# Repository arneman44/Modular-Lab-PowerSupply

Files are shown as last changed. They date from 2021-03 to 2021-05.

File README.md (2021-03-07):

# Project Modular lab powersupply
Arne Van den Broeck

## Desciption
A Modular lab bench powersupply 

### Specs Modules:
* use the eurocard format
* connected via a 40 ribbon cable as a bus 
* its own isolated powersupply 

## Modules:

### Powermodule:
* 0-30V
* 0-3A
* 16bit readout
* 12bit Controll
* Dual powerbus for connecting modules internally

### controller:
* 7inch touchscreen
* Ethernet
* USB host/device
* rotary Encoder

## Future modules:
* DC load
* Waveform generator
* Multimeter
* GPIO

## Files 
All the Kicad files where made using the nightly build of kicad
Version: (5.99.0-9544-g366189b864)

The STM32 project are build with cubeMX with as toolchain makefile.
I use vscode with STM32-for-vscode to build it

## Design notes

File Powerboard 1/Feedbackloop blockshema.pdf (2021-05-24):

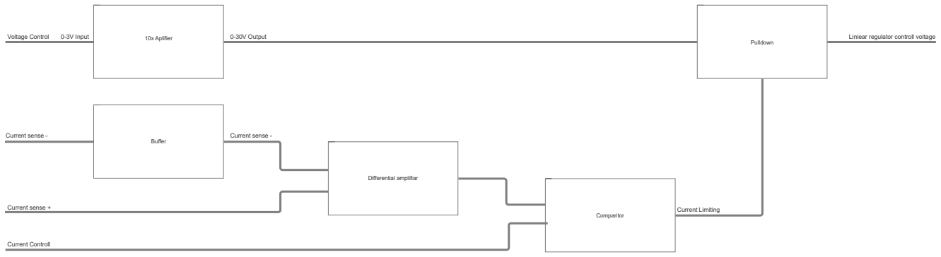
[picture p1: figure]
10x Aplifier; Buffer; Voltage Control; 0-3V Input; 0-30V Output; Pulldown; Current sense -; Current sense +; Differential amplifiar; Comparitor; Current Controll; Liniear regulator controll voltage; Current Limiting

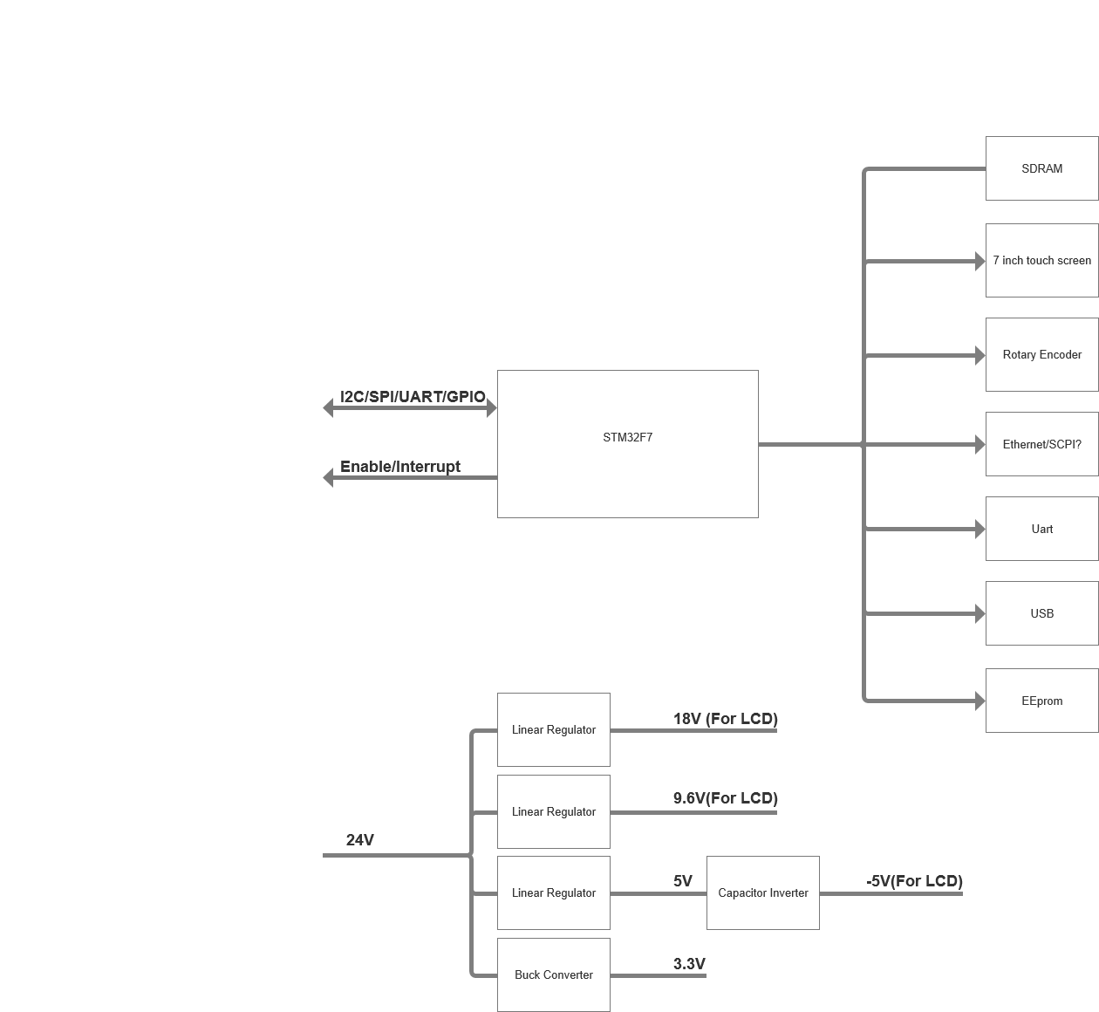
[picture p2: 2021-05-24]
Docs/contoller.png

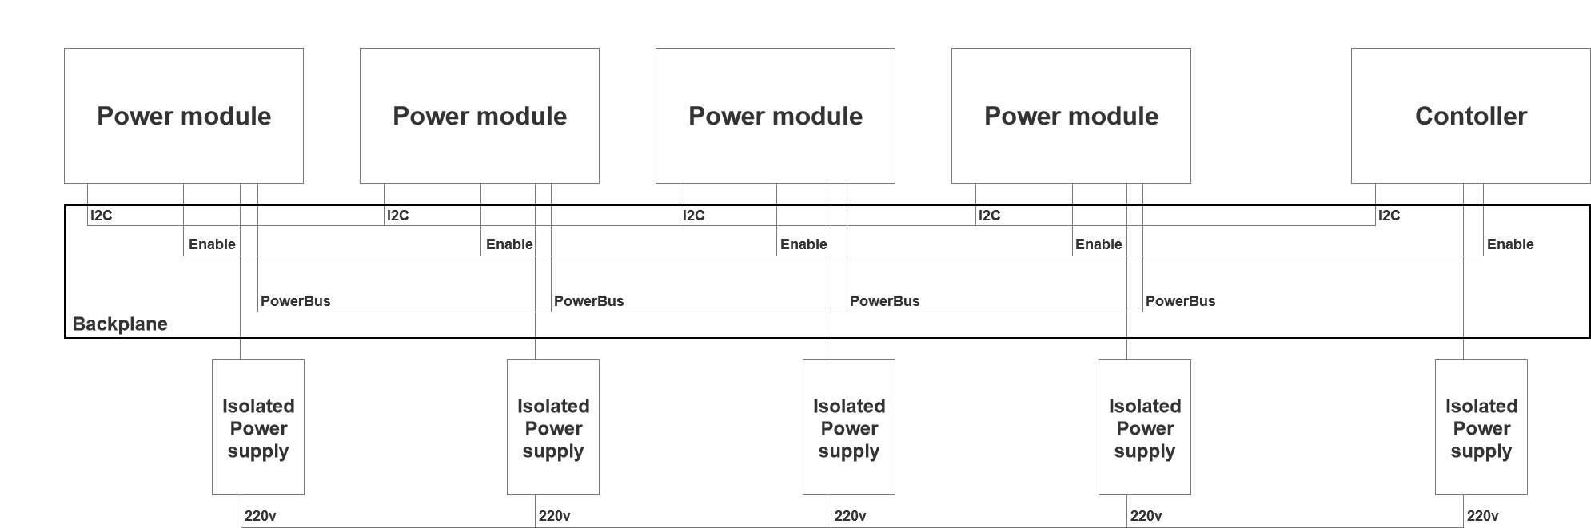
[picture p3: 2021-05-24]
Docs/power_supply.png

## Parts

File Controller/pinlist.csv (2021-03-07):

Position | Name | Type | Signal | Label | AF0 | AF1 | AF2 | AF3 | AF4 | AF5 | AF6 | AF7 | AF8 | AF9 | AF10 | AF11 | AF12 | AF13 | AF14
1 | PE2 | I/O |  |  | SYS_TRACECLK |  |  |  |  | SPI4_SCK | SAI1_MCLK_A |  |  | QUADSPI_BK1_IO2 |  | ETH_TXD3 | FMC_A23
2 | PE3 | I/O |  |  | SYS_TRACED0 |  |  |  |  |  | SAI1_SD_B |  |  |  |  |  | FMC_A19
3 | PE4 | I/O | LTDC_B0 |  | SYS_TRACED1 |  |  |  |  | SPI4_NSS | SAI1_FS_A |  |  |  |  |  | FMC_A20 | DCMI_D4 | LTDC_B0
4 | PE5 | I/O | LTDC_G0 |  | SYS_TRACED2 |  |  | TIM9_CH1 |  | SPI4_MISO | SAI1_SCK_A |  |  |  |  |  | FMC_A21 | DCMI_D6 | LTDC_G0
5 | PE6 | I/O | LTDC_G1 |  | SYS_TRACED3 | TIM1_BKIN2 |  | TIM9_CH2 |  | SPI4_MOSI | SAI1_SD_A |  |  |  | SAI2_MCLK_B |  | FMC_A22 | DCMI_D7 | LTDC_G1
6 | VBAT | Power
7 | PI8 | I/O
8 | PC13 | I/O
9 | PC14/OSC32_IN | I/O | RCC_OSC32_IN
10 | PC15/OSC32_OUT | I/O | RCC_OSC32_OUT
11 | PI9 | I/O | LTDC_VSYNC |  |  |  |  |  |  |  |  |  |  | CAN1_RX |  |  | FMC_D30 |  | LTDC_VSYNC
12 | PI10 | I/O | LTDC_HSYNC |  |  |  |  |  |  |  |  |  |  |  |  | ETH_RX_ER | FMC_D31 |  | LTDC_HSYNC
13 | PI11 | I/O |  |  |  |  |  |  |  |  |  |  |  |  | USB_OTG_HS_ULPI_DIR
14 | VSS | Power
15 | VDD | Power
16 | PF0 | I/O | I2C2_SDA |  |  |  |  |  | I2C2_SDA |  |  |  |  |  |  |  | FMC_A0
17 | PF1 | I/O | I2C2_SCL |  |  |  |  |  | I2C2_SCL |  |  |  |  |  |  |  | FMC_A1
18 | PF2 | I/O |  |  |  |  |  |  | I2C2_SMBA |  |  |  |  |  |  |  | FMC_A2
19 | PF3 | I/O |  |  |  |  |  |  |  |  |  |  |  |  |  |  | FMC_A3
20 | PF4 | I/O |  |  |  |  |  |  |  |  |  |  |  |  |  |  | FMC_A4
21 | PF5 | I/O |  |  |  |  |  |  |  |  |  |  |  |  |  |  | FMC_A5
22 | VSS | Power
23 | VDD | Power
24 | PF6 | I/O | UART7_RX |  |  |  |  | TIM10_CH1 |  | SPI5_NSS | SAI1_SD_B |  | UART7_RX | QUADSPI_BK1_IO3
25 | PF7 | I/O | UART7_TX |  |  |  |  | TIM11_CH1 |  | SPI5_SCK | SAI1_MCLK_B |  | UART7_TX | QUADSPI_BK1_IO2
26 | PF8 | I/O |  |  |  |  |  |  |  | SPI5_MISO | SAI1_SCK_B |  | UART7_DE/UART7_RTS | TIM13_CH1 | QUADSPI_BK1_IO0
27 | PF9 | I/O |  |  |  |  |  |  |  | SPI5_MOSI | SAI1_FS_B |  | UART7_CTS | TIM14_CH1 | QUADSPI_BK1_IO1
28 | PF10 | I/O | LTDC_DE |  |  |  |  |  |  |  |  |  |  |  |  |  |  | DCMI_D11 | LTDC_DE
29 | PH0/OSC_IN | I/O | RCC_OSC_IN
30 | PH1/OSC_OUT | I/O | RCC_OSC_OUT
31 | NRST | Reset
32 | PC0 | I/O | LTDC_R5 |  |  |  |  |  |  |  |  |  | SAI2_FS_B |  | USB_OTG_HS_ULPI_STP |  | FMC_SDNWE |  | LTDC_R5
33 | PC1 | I/O | ETH_MDC |  | SYS_TRACED0 |  |  |  |  | I2S2_SD/SPI2_MOSI | SAI1_SD_A |  |  |  |  | ETH_MDC
34 | PC2 | I/O | SPI2_MISO |  |  |  |  |  |  | SPI2_MISO |  |  |  |  | USB_OTG_HS_ULPI_DIR | ETH_TXD2 | FMC_SDNE0
35 | PC3 | I/O | SPI2_MOSI |  |  |  |  |  |  | I2S2_SD/SPI2_MOSI |  |  |  |  | USB_OTG_HS_ULPI_NXT | ETH_TX_CLK | FMC_SDCKE0
36 | VDD | Power
37 | VSSA | Power
38 | VREF+ | Power
39 | VDDA | Power
40 | PA0/WKUP | I/O | UART4_TX |  |  | TIM2_CH1/TIM2_ETR | TIM5_CH1 | TIM8_ETR |  |  |  | USART2_CTS | UART4_TX |  | SAI2_SD_B | ETH_CRS
41 | PA1 | I/O | ETH_REF_CLK |  |  | TIM2_CH2 | TIM5_CH2 |  |  |  |  | USART2_DE/USART2_RTS | UART4_RX | QUADSPI_BK1_IO3 | SAI2_MCLK_B | ETH_REF_CLK/ETH_RX_CLK |  |  | LTDC_R2
42 | PA2 | I/O | ETH_MDIO |  |  | TIM2_CH3 | TIM5_CH3 | TIM9_CH1 |  |  |  | USART2_TX | SAI2_SCK_B |  |  | ETH_MDIO |  |  | LTDC_R1
43 | PH2 | I/O | LTDC_R0 |  |  |  |  | LPTIM1_IN2 |  |  |  |  |  | QUADSPI_BK2_IO0 | SAI2_SCK_B | ETH_CRS | FMC_SDCKE0 |  | LTDC_R0
44 | PH3 | I/O | LTDC_R1 |  |  |  |  |  |  |  |  |  |  | QUADSPI_BK2_IO1 | SAI2_MCLK_B | ETH_COL | FMC_SDNE0 |  | LTDC_R1
45 | PH4 | I/O |  |  |  |  |  |  | I2C2_SCL |  |  |  |  |  | USB_OTG_HS_ULPI_NXT
46 | PH5 | I/O |  |  |  |  |  |  | I2C2_SDA | SPI5_NSS |  |  |  |  |  |  | FMC_SDNWE
47 | PA3 | I/O | USART2_RX |  |  | TIM2_CH4 | TIM5_CH4 | TIM9_CH2 |  |  |  | USART2_RX |  |  | USB_OTG_HS_ULPI_D0 | ETH_COL |  |  | LTDC_B5
48 | BYPASS_REG | Reset
49 | VDD | Power
50 | PA4 | I/O | DAC_OUT1 |  |  |  |  |  |  | I2S1_WS/SPI1_NSS | I2S3_WS/SPI3_NSS | USART2_CK |  |  |  |  | USB_OTG_HS_SOF | DCMI_HSYNC | LTDC_VSYNC
51 | PA5 | I/O | SPI1_SCK |  |  | TIM2_CH1/TIM2_ETR |  | TIM8_CH1N |  | I2S1_CK/SPI1_SCK |  |  |  |  | USB_OTG_HS_ULPI_CK |  |  |  | LTDC_R4
52 | PA6 | I/O | LTDC_G2 |  |  | TIM1_BKIN | TIM3_CH1 | TIM8_BKIN |  | SPI1_MISO |  |  |  | TIM13_CH1 |  |  |  | DCMI_PIXCLK | LTDC_G2
53 | PA7 | I/O | ETH_CRS_DV |  |  | TIM1_CH1N | TIM3_CH2 | TIM8_CH1N |  | I2S1_SD/SPI1_MOSI |  |  |  | TIM14_CH1 |  | ETH_CRS_DV/ETH_RX_DV | FMC_SDNWE
54 | PC4 | I/O | ETH_RXD0 |  |  |  |  |  |  | I2S1_MCK |  |  | SPDIFRX_IN2 |  |  | ETH_RXD0 | FMC_SDNE0
55 | PC5 | I/O | ETH_RXD1 |  |  |  |  |  |  |  |  |  | SPDIFRX_IN3 |  |  | ETH_RXD1 | FMC_SDCKE0
56 | PB0 | I/O | LTDC_R3 |  |  | TIM1_CH2N | TIM3_CH3 | TIM8_CH2N |  |  |  |  | UART4_CTS | LTDC_R3 | USB_OTG_HS_ULPI_D1 | ETH_RXD2
57 | PB1 | I/O | LTDC_R6 |  |  | TIM1_CH3N | TIM3_CH4 | TIM8_CH3N |  |  |  |  |  | LTDC_R6 | USB_OTG_HS_ULPI_D2 | ETH_RXD3
58 | PB2 | I/O |  |  |  |  |  |  |  |  | SAI1_SD_A | I2S3_SD/SPI3_MOSI |  | QUADSPI_CLK
59 | PF11 | I/O |  |  |  |  |  |  |  | SPI5_MOSI |  |  |  |  | SAI2_SD_B |  | FMC_SDNRAS | DCMI_D12
60 | PF12 | I/O |  |  |  |  |  |  |  |  |  |  |  |  |  |  | FMC_A6
61 | VSS | Power
62 | VDD | Power
63 | PF13 | I/O |  |  |  |  |  |  | I2C4_SMBA |  |  |  |  |  |  |  | FMC_A7
64 | PF14 | I/O |  |  |  |  |  |  | I2C4_SCL |  |  |  |  |  |  |  | FMC_A8
65 | PF15 | I/O |  |  |  |  |  |  | I2C4_SDA |  |  |  |  |  |  |  | FMC_A9
66 | PG0 | I/O |  |  |  |  |  |  |  |  |  |  |  |  |  |  | FMC_A10
67 | PG1 | I/O |  |  |  |  |  |  |  |  |  |  |  |  |  |  | FMC_A11
68 | PE7 | I/O |  |  |  | TIM1_ETR |  |  |  |  |  |  | UART7_RX |  | QUADSPI_BK2_IO0 |  | FMC_D4/FMC_DA4
69 | PE8 | I/O |  |  |  | TIM1_CH1N |  |  |  |  |  |  | UART7_TX |  | QUADSPI_BK2_IO1 |  | FMC_D5/FMC_DA5
70 | PE9 | I/O | TIM1_CH1 |  |  | TIM1_CH1 |  |  |  |  |  |  | UART7_DE/UART7_RTS |  | QUADSPI_BK2_IO2 |  | FMC_D6/FMC_DA6
71 | VSS | Power
72 | VDD | Power
73 | PE10 | I/O |  |  |  | TIM1_CH2N |  |  |  |  |  |  | UART7_CTS |  | QUADSPI_BK2_IO3 |  | FMC_D7/FMC_DA7
74 | PE11 | I/O | TIM1_CH2 |  |  | TIM1_CH2 |  |  |  | SPI4_NSS |  |  |  |  | SAI2_SD_B |  | FMC_D8/FMC_DA8 |  | LTDC_G3
75 | PE12 | I/O | LTDC_B4 |  |  | TIM1_CH3N |  |  |  | SPI4_SCK |  |  |  |  | SAI2_SCK_B |  | FMC_D9/FMC_DA9 |  | LTDC_B4
76 | PE13 | I/O | TIM1_CH3 |  |  | TIM1_CH3 |  |  |  | SPI4_MISO |  |  |  |  | SAI2_FS_B |  | FMC_D10/FMC_DA10 |  | LTDC_DE
77 | PE14 | I/O | TIM1_CH4 |  |  | TIM1_CH4 |  |  |  | SPI4_MOSI |  |  |  |  | SAI2_MCLK_B |  | FMC_D11/FMC_DA11 |  | LTDC_CLK
78 | PE15 | I/O | LTDC_R7 |  |  | TIM1_BKIN |  |  |  |  |  |  |  |  |  |  | FMC_D12/FMC_DA12 |  | LTDC_R7
79 | PB10 | I/O | TIM2_CH3 |  |  | TIM2_CH3 |  |  | I2C2_SCL | I2S2_CK/SPI2_SCK |  | USART3_TX |  |  | USB_OTG_HS_ULPI_D3 | ETH_RX_ER |  |  | LTDC_G4
80 | PB11 | I/O | TIM2_CH4 |  |  | TIM2_CH4 |  |  | I2C2_SDA |  |  | USART3_RX |  |  | USB_OTG_HS_ULPI_D4 | ETH_TX_EN |  |  | LTDC_G5
81 | VCAP_1 | Power
82 | VDD | Power
83 | PH6 | I/O |  |  |  |  |  |  | I2C2_SMBA | SPI5_SCK |  |  |  | TIM12_CH1 |  | ETH_RXD2 | FMC_SDNE1 | DCMI_D8
84 | PH7 | I/O | I2C3_SCL |  |  |  |  |  | I2C3_SCL | SPI5_MISO |  |  |  |  |  | ETH_RXD3 | FMC_SDCKE1 | DCMI_D9
85 | PH8 | I/O | LTDC_R2 |  |  |  |  |  | I2C3_SDA |  |  |  |  |  |  |  | FMC_D16 | DCMI_HSYNC | LTDC_R2
86 | PH9 | I/O |  |  |  |  |  |  | I2C3_SMBA |  |  |  |  | TIM12_CH2 |  |  | FMC_D17 | DCMI_D0 | LTDC_R3
87 | PH10 | I/O | LTDC_R4 |  |  |  | TIM5_CH1 |  | I2C4_SMBA |  |  |  |  |  |  |  | FMC_D18 | DCMI_D1 | LTDC_R4
88 | PH11 | I/O |  |  |  |  | TIM5_CH2 |  | I2C4_SCL |  |  |  |  |  |  |  | FMC_D19 | DCMI_D2 | LTDC_R5
89 | PH12 | I/O |  |  |  |  | TIM5_CH3 |  | I2C4_SDA |  |  |  |  |  |  |  | FMC_D20 | DCMI_D3 | LTDC_R6
90 | VSS | Power
91 | VDD | Power
92 | PB12 | I/O | ETH_TXD0 |  |  | TIM1_BKIN |  |  | I2C2_SMBA | I2S2_WS/SPI2_NSS |  | USART3_CK |  | CAN2_RX | USB_OTG_HS_ULPI_D5 | ETH_TXD0 | USB_OTG_HS_ID
93 | PB13 | I/O | ETH_TXD1 |  |  | TIM1_CH1N |  |  |  | I2S2_CK/SPI2_SCK |  | USART3_CTS |  | CAN2_TX | USB_OTG_HS_ULPI_D6 | ETH_TXD1
94 | PB14 | I/O |  |  |  | TIM1_CH2N |  | TIM8_CH2N |  | SPI2_MISO |  | USART3_DE/USART3_RTS |  | TIM12_CH1 |  |  | USB_OTG_HS_DM
95 | PB15 | I/O |  |  | RTC_REFIN | TIM1_CH3N |  | TIM8_CH3N |  | I2S2_SD/SPI2_MOSI |  |  |  | TIM12_CH2 |  |  | USB_OTG_HS_DP
96 | PD8 | I/O | USART3_TX |  |  |  |  |  |  |  |  | USART3_TX | SPDIFRX_IN1 |  |  |  | FMC_D13/FMC_DA13
97 | PD9 | I/O | USART3_RX |  |  |  |  |  |  |  |  | USART3_RX |  |  |  |  | FMC_D14/FMC_DA14
98 | PD10 | I/O | LTDC_B3 |  |  |  |  |  |  |  |  | USART3_CK |  |  |  |  | FMC_D15/FMC_DA15 |  | LTDC_B3
99 | PD11 | I/O |  |  |  |  |  |  | I2C4_SMBA |  |  | USART3_CTS |  | QUADSPI_BK1_IO0 | SAI2_SD_A |  | FMC_A16/FMC_CLE
100 | PD12 | I/O |  |  |  |  | TIM4_CH1 | LPTIM1_IN1 | I2C4_SCL |  |  | USART3_DE/USART3_RTS |  | QUADSPI_BK1_IO1 | SAI2_FS_A |  | FMC_A17/FMC_ALE
101 | PD13 | I/O |  |  |  |  | TIM4_CH2 | LPTIM1_OUT | I2C4_SDA |  |  |  |  | QUADSPI_BK1_IO3 | SAI2_SCK_A |  | FMC_A18
102 | VSS | Power
103 | VDD | Power
104 | PD14 | I/O |  |  |  |  | TIM4_CH3 |  |  |  |  |  | UART8_CTS |  |  |  | FMC_D0/FMC_DA0
105 | PD15 | I/O |  |  |  |  | TIM4_CH4 |  |  |  |  |  | UART8_DE/UART8_RTS |  |  |  | FMC_D1/FMC_DA1
106 | PG2 | I/O |  |  |  |  |  |  |  |  |  |  |  |  |  |  | FMC_A12
107 | PG3 | I/O |  |  |  |  |  |  |  |  |  |  |  |  |  |  | FMC_A13
108 | PG4 | I/O |  |  |  |  |  |  |  |  |  |  |  |  |  |  | FMC_A14/FMC_BA0
109 | PG5 | I/O |  |  |  |  |  |  |  |  |  |  |  |  |  |  | FMC_A15/FMC_BA1
110 | PG6 | I/O |  |  |  |  |  |  |  |  |  |  |  |  |  |  |  | DCMI_D12 | LTDC_R7
111 | PG7 | I/O | LTDC_CLK |  |  |  |  |  |  |  |  |  | USART6_CK |  |  |  | FMC_INT | DCMI_D13 | LTDC_CLK
112 | PG8 | I/O |  |  |  |  |  |  |  | SPI6_NSS |  | SPDIFRX_IN2 | USART6_DE/USART6_RTS |  |  | ETH_PPS_OUT | FMC_SDCLK
113 | VSS | Power
114 | VDDUSB | Power
115 | PC6 | I/O | TIM8_CH1 |  |  |  | TIM3_CH1 | TIM8_CH1 |  | I2S2_MCK |  |  | USART6_TX |  |  |  | SDMMC1_D6 | DCMI_D0 | LTDC_HSYNC
116 | PC7 | I/O | TIM8_CH2 |  |  |  | TIM3_CH2 | TIM8_CH2 |  |  | I2S3_MCK |  | USART6_RX |  |  |  | SDMMC1_D7 | DCMI_D1 | LTDC_G6
117 | PC8 | I/O |  |  | SYS_TRACED1 |  | TIM3_CH3 | TIM8_CH3 |  |  |  | UART5_DE/UART5_RTS | USART6_CK |  |  |  | SDMMC1_D0 | DCMI_D2
118 | PC9 | I/O | I2C3_SDA |  | RCC_MCO_2 |  | TIM3_CH4 | TIM8_CH4 | I2C3_SDA | I2S_CKIN |  | UART5_CTS |  | QUADSPI_BK1_IO0 |  |  | SDMMC1_D1 | DCMI_D3
119 | PA8 | I/O |  |  | RCC_MCO_1 | TIM1_CH1 |  | TIM8_BKIN2 | I2C3_SCL |  |  | USART1_CK |  |  | USB_OTG_FS_SOF |  |  |  | LTDC_R6
120 | PA9 | I/O | USART1_TX |  |  | TIM1_CH2 |  |  | I2C3_SMBA | I2S2_CK/SPI2_SCK |  | USART1_TX |  |  |  |  |  | DCMI_D0
121 | PA10 | I/O |  |  |  | TIM1_CH3 |  |  |  |  |  | USART1_RX |  |  | USB_OTG_FS_ID |  |  | DCMI_D1
122 | PA11 | I/O | USB_OTG_FS_DM |  |  | TIM1_CH4 |  |  |  |  |  | USART1_CTS |  | CAN1_RX | USB_OTG_FS_DM |  |  |  | LTDC_R4
123 | PA12 | I/O | USB_OTG_FS_DP |  |  | TIM1_ETR |  |  |  |  |  | USART1_DE/USART1_RTS | SAI2_FS_B | CAN1_TX | USB_OTG_FS_DP |  |  |  | LTDC_R5
124 | PA13 | I/O | SYS_JTMS-SWDIO |  | SYS_JTMS-SWDIO
125 | VCAP_2 | Power
126 | VSS | Power
127 | VDD | Power
128 | PH13 | I/O |  |  |  |  |  | TIM8_CH1N |  |  |  |  |  | CAN1_TX |  |  | FMC_D21 |  | LTDC_G2
129 | PH14 | I/O | LTDC_G3 |  |  |  |  | TIM8_CH2N |  |  |  |  |  |  |  |  | FMC_D22 | DCMI_D4 | LTDC_G3
130 | PH15 | I/O | LTDC_G4 |  |  |  |  | TIM8_CH3N |  |  |  |  |  |  |  |  | FMC_D23 | DCMI_D11 | LTDC_G4
131 | PI0 | I/O | LTDC_G5 |  |  |  | TIM5_CH4 |  |  | I2S2_WS/SPI2_NSS |  |  |  |  |  |  | FMC_D24 | DCMI_D13 | LTDC_G5
132 | PI1 | I/O | LTDC_G6 |  |  |  |  | TIM8_BKIN2 |  | I2S2_CK/SPI2_SCK |  |  |  |  |  |  | FMC_D25 | DCMI_D8 | LTDC_G6
133 | PI2 | I/O | LTDC_G7 |  |  |  |  | TIM8_CH4 |  | SPI2_MISO |  |  |  |  |  |  | FMC_D26 | DCMI_D9 | LTDC_G7
134 | PI3 | I/O |  |  |  |  |  | TIM8_ETR |  | I2S2_SD/SPI2_MOSI |  |  |  |  |  |  | FMC_D27 | DCMI_D10
135 | VSS | Power
136 | VDD | Power
137 | PA14 | I/O | SYS_JTCK-SWCLK |  | SYS_JTCK-SWCLK
138 | PA15 | I/O | TIM2_CH1 |  | SYS_JTDI | TIM2_CH1/TIM2_ETR |  |  | CEC | I2S1_WS/SPI1_NSS | I2S3_WS/SPI3_NSS |  | UART4_DE/UART4_RTS
139 | PC10 | I/O |  |  |  |  |  |  |  |  | I2S3_CK/SPI3_SCK | USART3_TX | UART4_TX | QUADSPI_BK1_IO1 |  |  | SDMMC1_D2 | DCMI_D8 | LTDC_R2
140 | PC11 | I/O | UART4_RX |  |  |  |  |  |  |  | SPI3_MISO | USART3_RX | UART4_RX | QUADSPI_BK2_NCS |  |  | SDMMC1_D3 | DCMI_D4
141 | PC12 | I/O | UART5_TX |  | SYS_TRACED3 |  |  |  |  |  | I2S3_SD/SPI3_MOSI | USART3_CK | UART5_TX |  |  |  | SDMMC1_CK | DCMI_D9
142 | PD0 | I/O |  |  |  |  |  |  |  |  |  |  |  | CAN1_RX |  |  | FMC_D2/FMC_DA2
143 | PD1 | I/O |  |  |  |  |  |  |  |  |  |  |  | CAN1_TX |  |  | FMC_D3/FMC_DA3
144 | PD2 | I/O | UART5_RX |  | SYS_TRACED2 |  | TIM3_ETR |  |  |  |  |  | UART5_RX |  |  |  | SDMMC1_CMD | DCMI_D11
145 | PD3 | I/O | SPI2_SCK |  |  |  |  |  |  | I2S2_CK/SPI2_SCK |  | USART2_CTS |  |  |  |  | FMC_CLK | DCMI_D5 | LTDC_G7
146 | PD4 | I/O |  |  |  |  |  |  |  |  |  | USART2_DE/USART2_RTS |  |  |  |  | FMC_NOE
147 | PD5 | I/O | USART2_TX |  |  |  |  |  |  |  |  | USART2_TX |  |  |  |  | FMC_NWE
148 | VSS | Power
149 | VDD | Power
150 | PD6 | I/O | LTDC_B2 |  |  |  |  |  |  | I2S3_SD/SPI3_MOSI | SAI1_SD_A | USART2_RX |  |  |  |  | FMC_NWAIT | DCMI_D10 | LTDC_B2
151 | PD7 | I/O |  |  |  |  |  |  |  |  |  | USART2_CK | SPDIFRX_IN0 |  |  |  | FMC_NE1
152 | PG9 | I/O | USART6_RX |  |  |  |  |  |  |  |  | SPDIFRX_IN3 | USART6_RX | QUADSPI_BK2_IO2 | SAI2_FS_B |  | FMC_NCE/FMC_NE2 | DCMI_VSYNC
153 | PG10 | I/O |  |  |  |  |  |  |  |  |  |  |  | LTDC_G3 | SAI2_SD_B |  | FMC_NE3 | DCMI_D2 | LTDC_B2
154 | PG11 | I/O | ETH_TX_EN |  |  |  |  |  |  |  |  | SPDIFRX_IN0 |  |  |  | ETH_TX_EN |  | DCMI_D3 | LTDC_B3
155 | PG12 | I/O | LTDC_B1 |  |  |  |  | LPTIM1_IN1 |  | SPI6_MISO |  | SPDIFRX_IN1 | USART6_DE/USART6_RTS | LTDC_B4 |  |  | FMC_NE4 |  | LTDC_B1
156 | PG13 | I/O |  |  | SYS_TRACED0 |  |  | LPTIM1_OUT |  | SPI6_SCK |  |  | USART6_CTS |  |  | ETH_TXD0 | FMC_A24 |  | LTDC_R0
157 | PG14 | I/O | USART6_TX |  | SYS_TRACED1 |  |  | LPTIM1_ETR |  | SPI6_MOSI |  |  | USART6_TX | QUADSPI_BK2_IO3 |  | ETH_TXD1 | FMC_A25 |  | LTDC_B0
158 | VSS | Power
159 | VDD | Power
160 | PG15 | I/O |  |  |  |  |  |  |  |  |  |  | USART6_CTS |  |  |  | FMC_SDNCAS | DCMI_D13
161 | PB3 | I/O | TIM2_CH2 |  | SYS_JTDO-SWO | TIM2_CH2 |  |  |  | I2S1_CK/SPI1_SCK | I2S3_CK/SPI3_SCK
162 | PB4 | I/O | SPI1_MISO |  | SYS_JTRST |  | TIM3_CH1 |  |  | SPI1_MISO | SPI3_MISO | I2S2_WS/SPI2_NSS
163 | PB5 | I/O | SPI1_MOSI |  |  |  | TIM3_CH2 |  | I2C1_SMBA | I2S1_SD/SPI1_MOSI | I2S3_SD/SPI3_MOSI |  |  | CAN2_RX | USB_OTG_HS_ULPI_D7 | ETH_PPS_OUT | FMC_SDCKE1 | DCMI_D10
164 | PB6 | I/O | I2C1_SCL |  |  |  | TIM4_CH1 | CEC | I2C1_SCL |  |  | USART1_TX |  | CAN2_TX | QUADSPI_BK1_NCS |  | FMC_SDNE1 | DCMI_D5
165 | PB7 | I/O | USART1_RX |  |  |  | TIM4_CH2 |  | I2C1_SDA |  |  | USART1_RX |  |  |  |  | FMC_NL | DCMI_VSYNC
166 | BOOT0 | Boot
167 | PB8 | I/O | LTDC_B6 |  |  |  | TIM4_CH3 | TIM10_CH1 | I2C1_SCL |  |  |  |  | CAN1_RX |  | ETH_TXD3 | SDMMC1_D4 | DCMI_D6 | LTDC_B6
168 | PB9 | I/O | I2C1_SDA |  |  |  | TIM4_CH4 | TIM11_CH1 | I2C1_SDA | I2S2_WS/SPI2_NSS |  |  |  | CAN1_TX |  |  | SDMMC1_D5 | DCMI_D7 | LTDC_B7
169 | PE0 | I/O | UART8_RX |  |  |  | TIM4_ETR | LPTIM1_ETR |  |  |  |  | UART8_RX |  | SAI2_MCLK_A |  | FMC_NBL0 | DCMI_D2
170 | PE1 | I/O | UART8_TX |  |  |  |  | LPTIM1_IN2 |  |  |  |  | UART8_TX |  |  |  | FMC_NBL1 | DCMI_D3
171 | PDR_ON | Reset
172 | VDD | Power
173 | PI4 | I/O |  |  |  |  |  | TIM8_BKIN |  |  |  |  |  |  | SAI2_MCLK_A |  | FMC_NBL2 | DCMI_D5 | LTDC_B4
174 | PI5 | I/O | LTDC_B5 |  |  |  |  | TIM8_CH1 |  |  |  |  |  |  | SAI2_SCK_A |  | FMC_NBL3 | DCMI_VSYNC | LTDC_B5
175 | PI6 | I/O |  |  |  |  |  | TIM8_CH2 |  |  |  |  |  |  | SAI2_SD_A |  | FMC_D28 | DCMI_D6 | LTDC_B6
176 | PI7 | I/O | LTDC_B7 |  |  |  |  | TIM8_CH3 |  |  |  |  |  |  | SAI2_FS_A |  | FMC_D29 | DCMI_D7 | LTDC_B7

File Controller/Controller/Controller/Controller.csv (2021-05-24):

Reference | Value | Footprint | Datasheet | LCSC | Partnr
C1 | 2.2µF ceramic | Capacitor_SMD:C_0805_2012Metric_Pad1.18x1.45mm_HandSolder | ~ | C77081
C2 | 2.2µF ceramic | Capacitor_SMD:C_0805_2012Metric_Pad1.18x1.45mm_HandSolder | ~ | C77081
C3 | 100nF | Capacitor_SMD:C_0805_2012Metric_Pad1.18x1.45mm_HandSolder | ~
C4 | 100nF | Capacitor_SMD:C_0805_2012Metric_Pad1.18x1.45mm_HandSolder | ~
C5 | 100nF | Capacitor_SMD:C_0805_2012Metric_Pad1.18x1.45mm_HandSolder | ~
C6 | 100nF | Capacitor_SMD:C_0805_2012Metric_Pad1.18x1.45mm_HandSolder | ~
C7 | 100nF | Capacitor_SMD:C_0805_2012Metric_Pad1.18x1.45mm_HandSolder | ~
C8 | 100nF | Capacitor_SMD:C_0805_2012Metric_Pad1.18x1.45mm_HandSolder | ~
C9 | 100nF | Capacitor_SMD:C_0805_2012Metric_Pad1.18x1.45mm_HandSolder | ~
C10 | 100nF | Capacitor_SMD:C_0805_2012Metric_Pad1.18x1.45mm_HandSolder | ~
C11 | 100nF | Capacitor_SMD:C_0805_2012Metric_Pad1.18x1.45mm_HandSolder | ~
C12 | 100nF | Capacitor_SMD:C_0805_2012Metric_Pad1.18x1.45mm_HandSolder | ~
C13 | 100nF | Capacitor_SMD:C_0805_2012Metric_Pad1.18x1.45mm_HandSolder | ~
C14 | 100nF | Capacitor_SMD:C_0805_2012Metric_Pad1.18x1.45mm_HandSolder | ~
C15 | 100nF | Capacitor_SMD:C_0805_2012Metric_Pad1.18x1.45mm_HandSolder | ~
C16 | 100nF | Capacitor_SMD:C_0805_2012Metric_Pad1.18x1.45mm_HandSolder | ~
C17 | 100nF | Capacitor_SMD:C_0805_2012Metric_Pad1.18x1.45mm_HandSolder | ~
C18 | 100nF | Capacitor_SMD:C_0805_2012Metric_Pad1.18x1.45mm_HandSolder | ~
C19 | 100nF | Capacitor_SMD:C_0805_2012Metric_Pad1.18x1.45mm_HandSolder | ~
C20 | 100nF | Capacitor_SMD:C_0805_2012Metric_Pad1.18x1.45mm_HandSolder | ~
C21 | 100nF | Capacitor_SMD:C_0805_2012Metric_Pad1.18x1.45mm_HandSolder | ~
C22 | 100nF | Capacitor_SMD:C_0805_2012Metric_Pad1.18x1.45mm_HandSolder | ~
C23 | 4.7pF | Capacitor_SMD:C_0805_2012Metric_Pad1.18x1.45mm_HandSolder | ~ | C1820
C24 | 100nF | Capacitor_SMD:C_0805_2012Metric_Pad1.18x1.45mm_HandSolder | ~
C25 | 100nF | Capacitor_SMD:C_0805_2012Metric_Pad1.18x1.45mm_HandSolder | ~
C26 | 100nF | Capacitor_SMD:C_0805_2012Metric_Pad1.18x1.45mm_HandSolder | ~
C27 | 100nF | Capacitor_SMD:C_0805_2012Metric_Pad1.18x1.45mm_HandSolder | ~
C40 | 4.7pF | Capacitor_SMD:C_0805_2012Metric_Pad1.18x1.45mm_HandSolder | ~ | C1820
C41 | 100nF | Capacitor_SMD:C_0805_2012Metric_Pad1.18x1.45mm_HandSolder | ~
C42 | 100nF | Capacitor_SMD:C_0805_2012Metric_Pad1.18x1.45mm_HandSolder | ~
C43 | 100nF | Capacitor_SMD:C_0805_2012Metric_Pad1.18x1.45mm_HandSolder | ~
C52 | 100nF | Capacitor_SMD:C_0805_2012Metric_Pad1.18x1.45mm_HandSolder | ~
C53 | 100nF | Capacitor_SMD:C_0805_2012Metric_Pad1.18x1.45mm_HandSolder | ~
C54 | 100nF | Capacitor_SMD:C_0805_2012Metric_Pad1.18x1.45mm_HandSolder | ~
C55 | 100nF | Capacitor_SMD:C_0805_2012Metric_Pad1.18x1.45mm_HandSolder | ~
C57 | 100nF | Capacitor_SMD:C_0805_2012Metric_Pad1.18x1.45mm_HandSolder | ~
C58 | 100nF | Capacitor_SMD:C_0805_2012Metric_Pad1.18x1.45mm_HandSolder | ~
J1 | Conn_01x02 | TerminalBlock:TerminalBlock_bornier-2_P5.08mm | ~
J2 | Conn_02x20_Counter_Clockwise | Connector_PinSocket_2.54mm:PinSocket_2x20_P2.54mm_Vertical | ~
J3 | Conn_01x06 | Connector_PinSocket_2.54mm:PinSocket_1x06_P2.54mm_Vertical | ~
J4 | Conn_01x05 | Connector_PinSocket_2.54mm:PinSocket_1x05_P2.54mm_Vertical | ~
J5 | USB_A | Connector_USB:USB_A_Molex_105057_Vertical | ~ | C586225
J6 | USB_C_Receptacle_USB2.0 | Connector_USB:USB_C_Receptacle_Palconn_UTC16-G | https://www.usb.org/sites/default/files/documents/usb_type-c.zip
J7 | RJ45_Amphenol_RJMG1BD3B8K1ANR | 00_Custom_Kicad:HR913550A | https://www.amphenolcanada.com/ProductSearch/Drawings/AC/RJMG1BD3B8K1ANR.PDF
J10 | Conn_01x03 | Connector_PinSocket_2.54mm:PinSocket_1x03_P2.54mm_Vertical | ~
R1 | 10Kohm | Resistor_SMD:R_0805_2012Metric_Pad1.20x1.40mm_HandSolder | ~
R2 | 10Kohm | Resistor_SMD:R_0805_2012Metric_Pad1.20x1.40mm_HandSolder | ~
R3 | 10Kohm | Resistor_SMD:R_0805_2012Metric_Pad1.20x1.40mm_HandSolder | ~
R4 | 10Kohm | Resistor_SMD:R_0805_2012Metric_Pad1.20x1.40mm_HandSolder | ~
R5 | 10Kohm | Resistor_SMD:R_0805_2012Metric_Pad1.20x1.40mm_HandSolder | ~
R6 | 10Kohm | Resistor_SMD:R_0805_2012Metric_Pad1.20x1.40mm_HandSolder | ~
R7 | 10Kohm | Resistor_SMD:R_0805_2012Metric_Pad1.20x1.40mm_HandSolder | ~
R8 | 22ohm | Resistor_SMD:R_0805_2012Metric_Pad1.20x1.40mm_HandSolder | ~
R9 | 22ohm | Resistor_SMD:R_0805_2012Metric_Pad1.20x1.40mm_HandSolder | ~
R10 | a | Resistor_SMD:R_0805_2012Metric_Pad1.20x1.40mm_HandSolder | ~
R11 | 12.1Kohm | Resistor_SMD:R_0805_2012Metric_Pad1.20x1.40mm_HandSolder | ~ | C17431
R12 | 10Kohm | Resistor_SMD:R_0805_2012Metric_Pad1.20x1.40mm_HandSolder | ~
R13 | 50ohm | Resistor_SMD:R_0805_2012Metric_Pad1.20x1.40mm_HandSolder | ~ | C204544
R14 | 4.7Kohm | Resistor_SMD:R_0805_2012Metric_Pad1.20x1.40mm_HandSolder | ~
R15 | 50ohm | Resistor_SMD:R_0805_2012Metric_Pad1.20x1.40mm_HandSolder | ~ | C204544
R16 | 4.7Kohm | Resistor_SMD:R_0805_2012Metric_Pad1.20x1.40mm_HandSolder | ~
R17 | 10Kohm | Resistor_SMD:R_0805_2012Metric_Pad1.20x1.40mm_HandSolder | ~
R18 | 4.7Kohm | Resistor_SMD:R_0805_2012Metric_Pad1.20x1.40mm_HandSolder | ~
R19 | 50ohm | Resistor_SMD:R_0805_2012Metric_Pad1.20x1.40mm_HandSolder | ~ | C204544
R20 | 4.7Kohm | Resistor_SMD:R_0805_2012Metric_Pad1.20x1.40mm_HandSolder | ~
R21 | 1.5Kohm | Resistor_SMD:R_0805_2012Metric_Pad1.20x1.40mm_HandSolder | ~
R22 | 50ohm | Resistor_SMD:R_0805_2012Metric_Pad1.20x1.40mm_HandSolder | ~ | C204544
R23 | 330ohm | Resistor_SMD:R_0805_2012Metric_Pad1.20x1.40mm_HandSolder | ~
R24 | 4.7Kohm | Resistor_SMD:R_0805_2012Metric_Pad1.20x1.40mm_HandSolder | ~
R25 | 330ohm | Resistor_SMD:R_0805_2012Metric_Pad1.20x1.40mm_HandSolder | ~
R26 | 47Kohm | Resistor_SMD:R_0805_2012Metric_Pad1.20x1.40mm_HandSolder | ~
R27 | 10Kohm | Resistor_SMD:R_0805_2012Metric_Pad1.20x1.40mm_HandSolder | ~
R28 | 10Kohm | Resistor_SMD:R_0805_2012Metric_Pad1.20x1.40mm_HandSolder | ~
R29 | 10Kohm | Resistor_SMD:R_0805_2012Metric_Pad1.20x1.40mm_HandSolder | ~
SW1 | SW_Push | Button_Switch_SMD:SW_Push_1P1T_NO_CK_KSC7xxJ | ~
SW2 | SW_Push | Button_Switch_SMD:SW_Push_1P1T_NO_CK_KSC7xxJ | ~
U1 | STM32F746IGTx | Package_QFP:LQFP-176_24x24mm_P0.5mm | http://www.st.com/st-web-ui/static/active/en/resource/technical/document/datasheet/DM00166116.pdf
U2 | LAN8720A | Package_DFN_QFN:QFN-24-1EP_4x4mm_P0.5mm_EP2.6x2.6mm | http://ww1.microchip.com/downloads/en/DeviceDoc/8720a.pdf | C17146
U3 | M24C02-WMN | Package_SO:SOIC-8_3.9x4.9mm_P1.27mm | http://www.st.com/content/ccc/resource/technical/document/datasheet/b0/d8/50/40/5a/85/49/6f/DM00071904.pdf/files/DM00071904.pdf/jcr:content/translations/en.DM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
U11 | IS42S16400J | Package_SO:TSOP-II-54_22.2x10.16mm_P0.8mm
X1 | XO32 | Oscillator:Oscillator_SMD_EuroQuartz_XO32-4Pin_3.2x2.5mm | http://cdn-reichelt.de/documents/datenblatt/B400/XO32.pdf | C387396
Y1 | 32.765Mhz | Crystal:Crystal_SMD_3215-2Pin_3.2x1.5mm | ~ | C271654
C28 | 330uF | Capacitor_SMD:CP_Elec_8x10 | ~ | C249647
C29 | 100nF | Capacitor_SMD:C_0805_2012Metric_Pad1.18x1.45mm_HandSolder | ~
C30 | 560pF | Capacitor_SMD:C_0805_2012Metric_Pad1.18x1.45mm_HandSolder | ~ | C1829
C31 | 6.8nF | Capacitor_SMD:C_0805_2012Metric_Pad1.18x1.45mm_HandSolder | ~ | C282778
C32 | 10µF | Capacitor_SMD:C_1206_3216Metric_Pad1.33x1.80mm_HandSolder | ~ | C17024
C33 | 10pF | Capacitor_SMD:C_0805_2012Metric_Pad1.18x1.45mm_HandSolder | ~ | C157608
C34 | 1µF | Capacitor_SMD:C_0805_2012Metric_Pad1.18x1.45mm_HandSolder | ~ | C50683
C35 | 100nF | Capacitor_SMD:C_0805_2012Metric_Pad1.18x1.45mm_HandSolder | ~
C36 | Optional | Capacitor_SMD:C_1206_3216Metric_Pad1.33x1.80mm_HandSolder | ~
C37 | 100pF | Capacitor_SMD:C_0805_2012Metric_Pad1.18x1.45mm_HandSolder | ~ | C82028
C38 | 100uF | Capacitor_SMD:CP_Elec_5x5.4 | ~
C39 | 270uF | Capacitor_SMD:CP_Elec_10x12.6 | ~ | C250070
C44 | 100uF | Capacitor_SMD:CP_Elec_5x5.4 | ~
C45 | 4.7uF | Capacitor_SMD:C_0805_2012Metric_Pad1.18x1.45mm_HandSolder | ~ | C415307
C46 | 100uF | Capacitor_SMD:CP_Elec_5x5.4 | ~
C47 | 4.7uF | Capacitor_SMD:C_0805_2012Metric_Pad1.18x1.45mm_HandSolder | ~ | C415307
C48 | 3.3uF | Capacitor_SMD:CP_Elec_4x5.7 | ~ | C249911
C49 | 100nF | Capacitor_SMD:C_0805_2012Metric_Pad1.18x1.45mm_HandSolder | ~
C50 | 100uF | Capacitor_SMD:CP_Elec_5x5.4 | ~
C51 | 4.7uF | Capacitor_SMD:C_0805_2012Metric_Pad1.18x1.45mm_HandSolder | ~ | C415307
C56 | 100nF | Capacitor_SMD:C_0805_2012Metric_Pad1.18x1.45mm_HandSolder | ~
C59 | 22uF | Capacitor_SMD:CP_Elec_3x5.3 | ~ | C249481
D1 | ss34 | Diode_SMD:D_SMA_Handsoldering | ~ | C83961
D2 | ss34 | Diode_SMD:D_SMA_Handsoldering | ~ | C83961
J8 | Conn_01x06_MountingPin | Connector_FFC-FPC:Hirose_FH12-6S-0.5SH_1x06-1MP_P0.50mm_Horizontal | ~ | C528032
J9 | Conn_01x50_MountingPin | 00_Custom_Kicad:FPC_50 | ~ | C11098
L1 | 68uH | Inductor_SMD:L_Bourns-SRN8040_8x8.15mm | ~ | C266439 | SMNR8040-680MT
L2 | 1.8uH | Inductor_SMD:L_6.3x6.3_H3 | ~ | C326333
L3 | 15uH | Inductor_SMD:L_10.4x10.4_H4.8 | ~ | C156417
Q1 | CSD16323Q3 | Package_TO_SOT_SMD:TDSON-8-1
R30 | 88.7Kohm | Resistor_SMD:R_0805_2012Metric_Pad1.20x1.40mm_HandSolder | ~ | C706252
R31 | 62Kohm | Resistor_SMD:R_0805_2012Metric_Pad1.20x1.40mm_HandSolder | ~ | C351556
R32 | 47Kohm | Resistor_SMD:R_0805_2012Metric_Pad1.20x1.40mm_HandSolder | ~
R33 | 10Kohm | Resistor_SMD:R_0805_2012Metric_Pad1.20x1.40mm_HandSolder | ~
R34 | 22.1Kohm | Resistor_SMD:R_0805_2012Metric_Pad1.20x1.40mm_HandSolder | ~ | C422851
R36 | 100ohm | Resistor_SMD:R_0805_2012Metric_Pad1.20x1.40mm_HandSolder | ~
R37 | 5mohm | Resistor_SMD:R_2512_6332Metric_Pad1.40x3.35mm_HandSolder | ~ | C782251
R38 | 0.7ohm | Resistor_SMD:R_1206_3216Metric_Pad1.30x1.75mm_HandSolder | ~ | C621283
R39 | 107Kohm | Resistor_SMD:R_0805_2012Metric_Pad1.20x1.40mm_HandSolder | ~ | C409944
R40 | 27.4Kohm | Resistor_SMD:R_0805_2012Metric_Pad1.20x1.40mm_HandSolder | ~ | C17587
R41 | 1Kohm | Resistor_SMD:R_0805_2012Metric_Pad1.20x1.40mm_HandSolder | ~
R42 | 13.3Kohm | Resistor_SMD:R_0805_2012Metric_Pad1.20x1.40mm_HandSolder | ~ | C103975
R43 | 147Kohm | Resistor_SMD:R_0805_2012Metric_Pad1.20x1.40mm_HandSolder | ~ | C170031
R44 | 21.5Kohm | Resistor_SMD:R_0805_2012Metric_Pad1.20x1.40mm_HandSolder | ~ | C706267
U4 | LM317_TO-252 | Package_TO_SOT_SMD:TO-252-2 | http://www.ti.com/lit/ds/snvs774n/snvs774n.pdf
U5 | AMS1117-3.3 | Package_TO_SOT_SMD:SOT-223-3_TabPin2 | http://www.advanced-monolithic.com/pdf/ds1117.pdf | C347222
U6 | LMR50410 | Package_TO_SOT_SMD:TSOT-23-6_HandSoldering |  | mouser
U7 | LM3488 | Package_SO:MSOP-8_3x3mm_P0.65mm |  | C80773
U8 | C85037 | Package_TO_SOT_SMD:SOT-89-5 | http://www.issi.com/WW/pdf/31LT3360.pdf
U9 | LM317_TO-252 | Package_TO_SOT_SMD:TO-252-2 | http://www.ti.com/lit/ds/snvs774n/snvs774n.pdf
U10 | LTC1261L | Package_SO:MSOP-8_3x3mm_P0.65mm

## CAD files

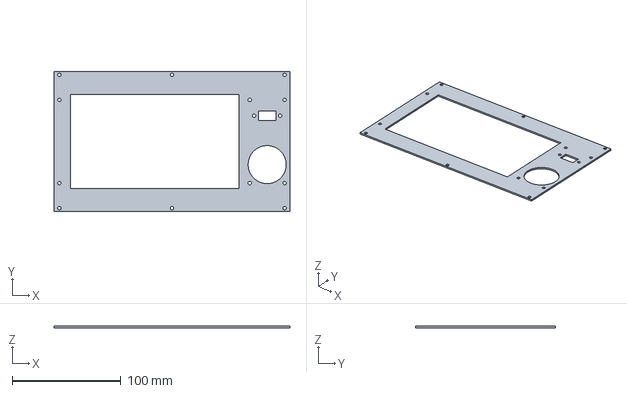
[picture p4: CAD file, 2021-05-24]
Controller/Controller Front/Controller Front/Controller Front.step
217.0 x 128.5 x 1.60 mm

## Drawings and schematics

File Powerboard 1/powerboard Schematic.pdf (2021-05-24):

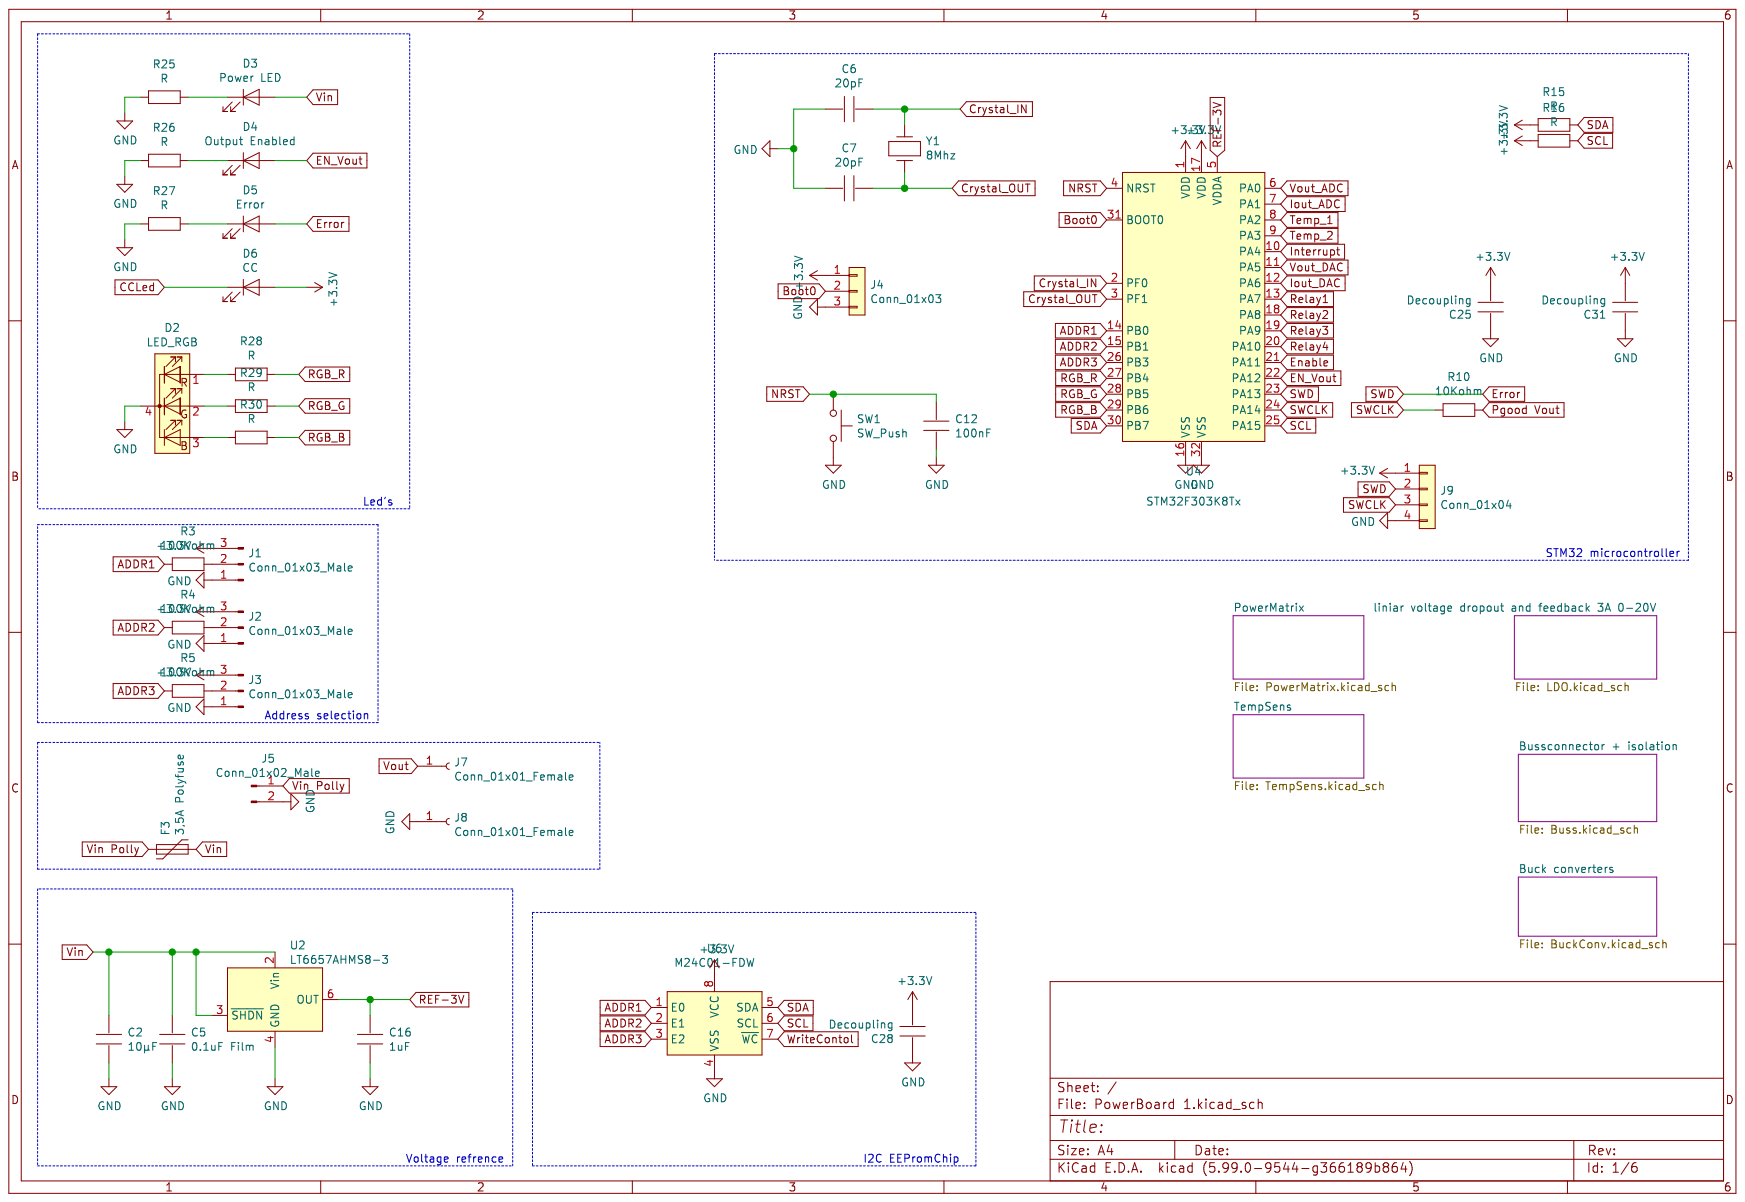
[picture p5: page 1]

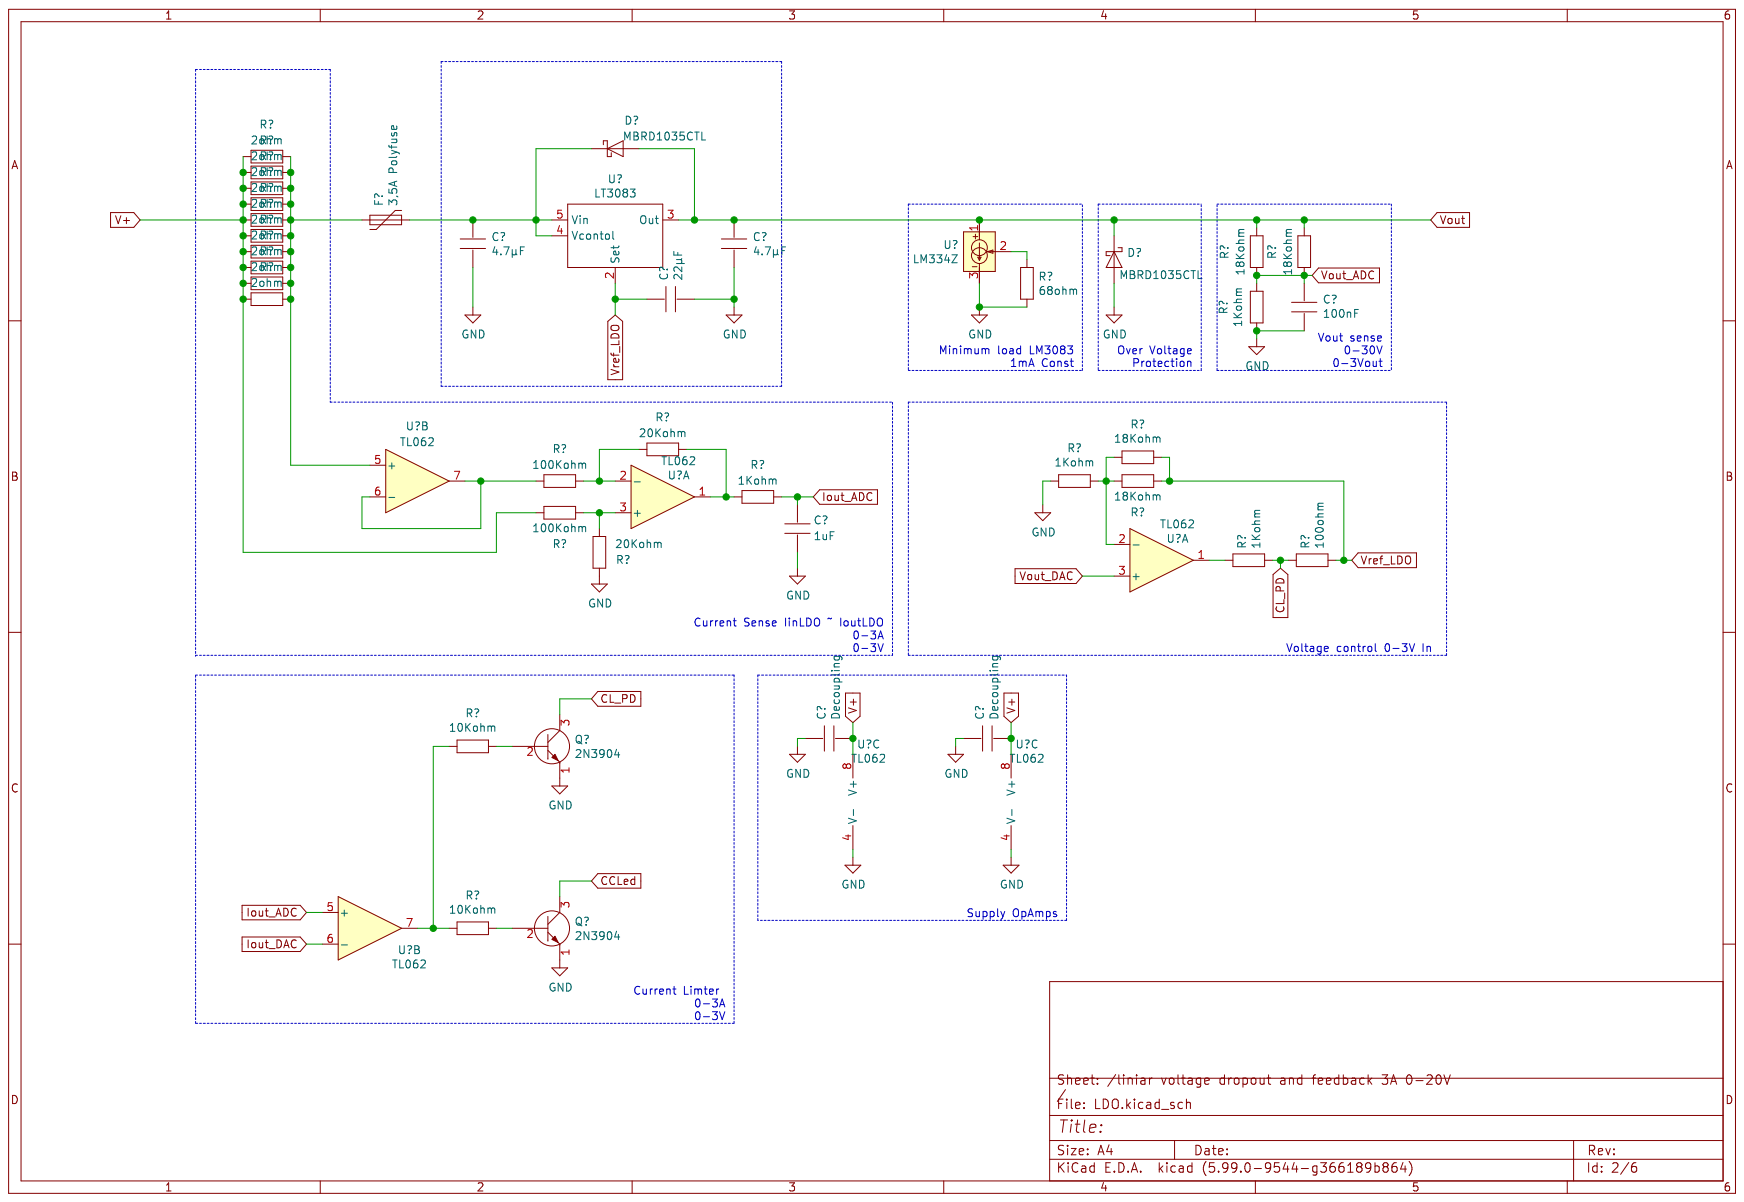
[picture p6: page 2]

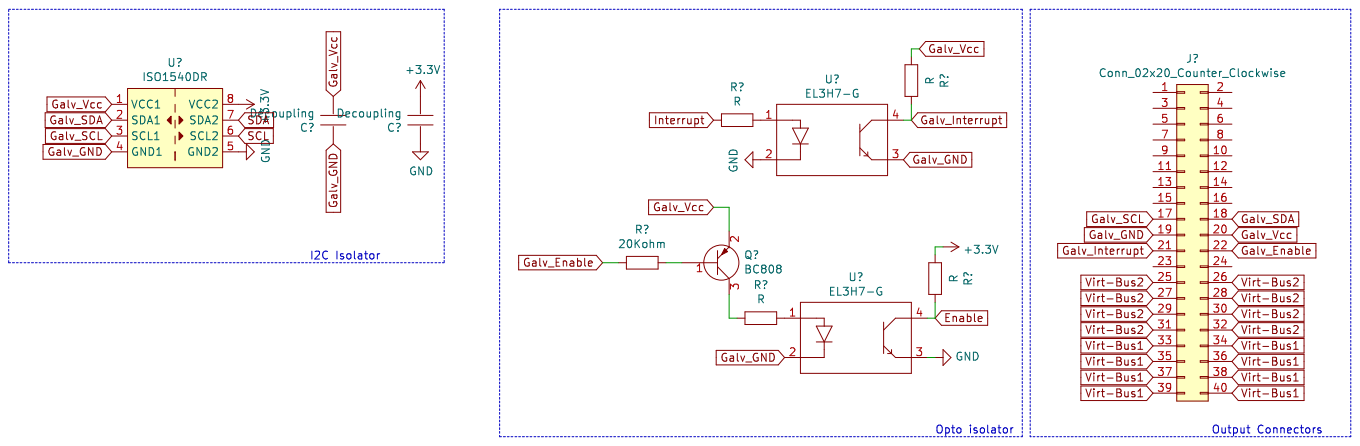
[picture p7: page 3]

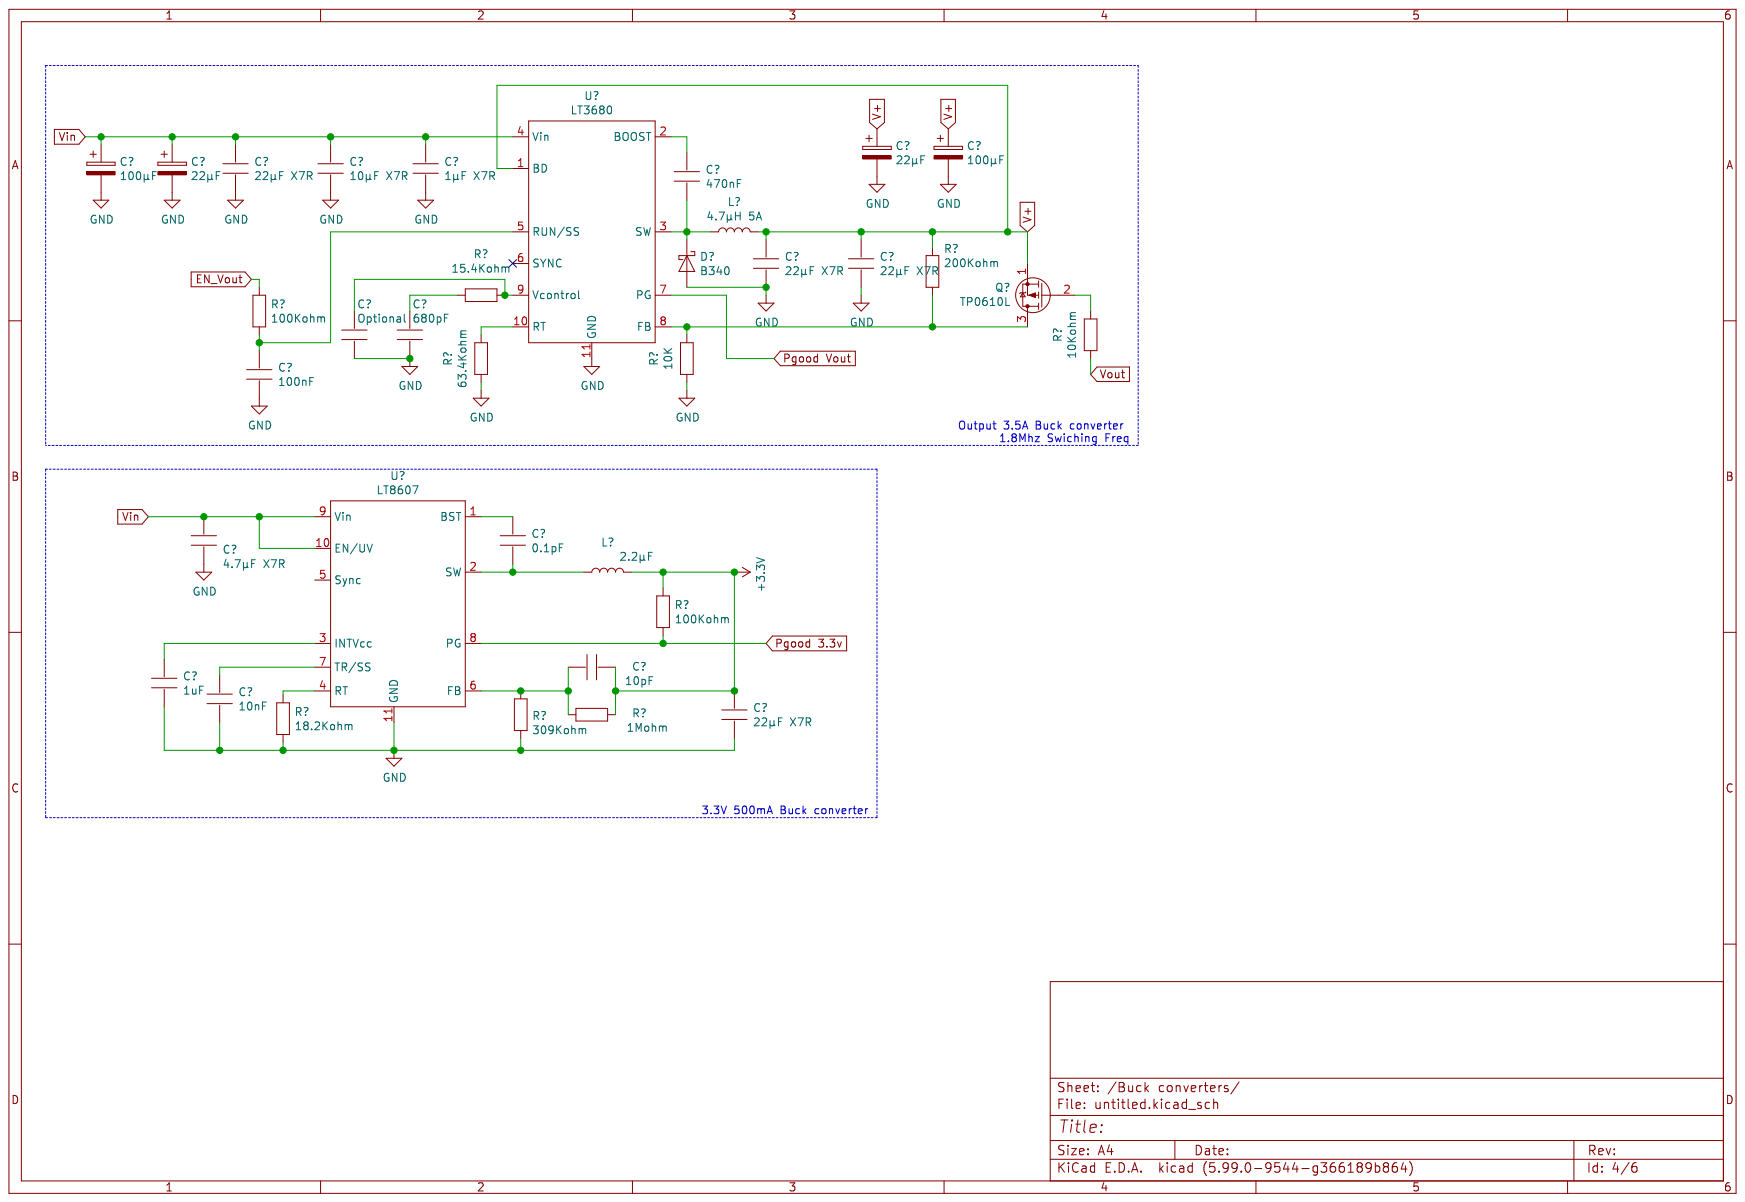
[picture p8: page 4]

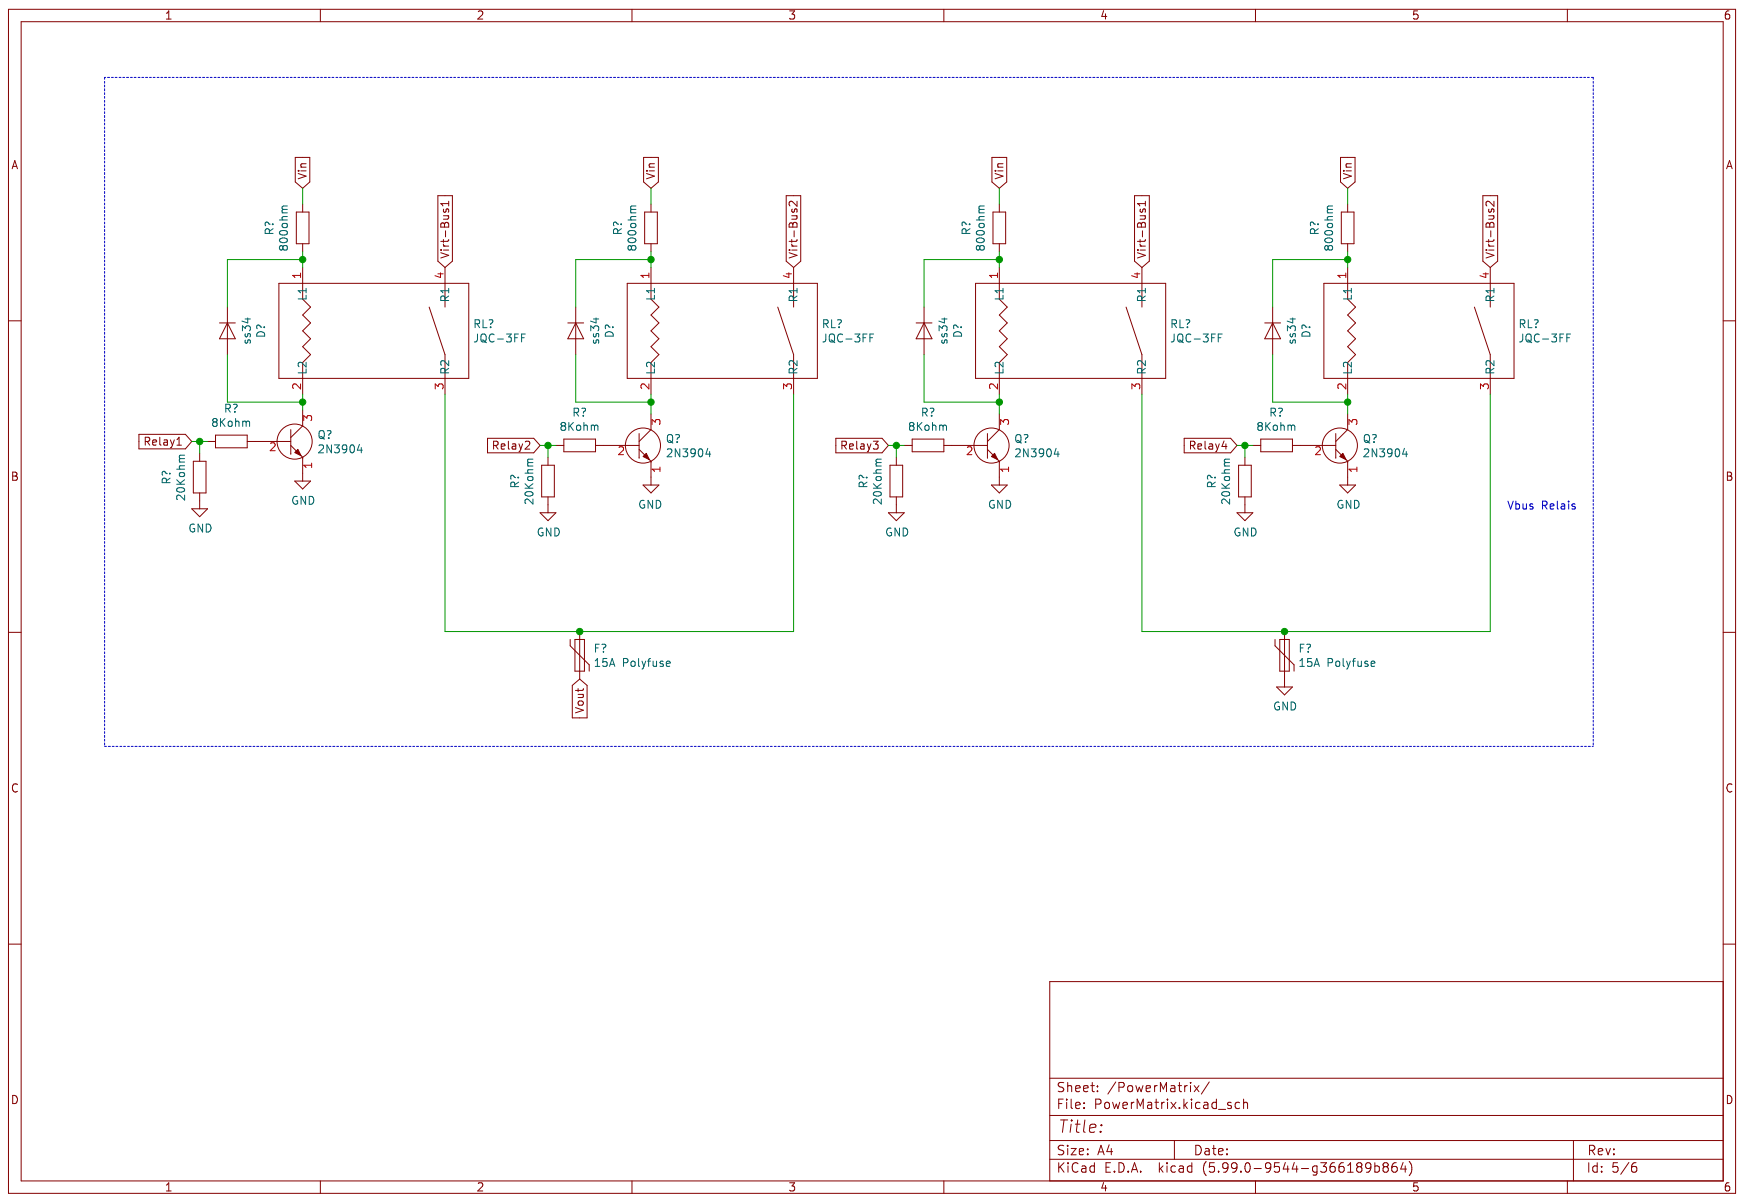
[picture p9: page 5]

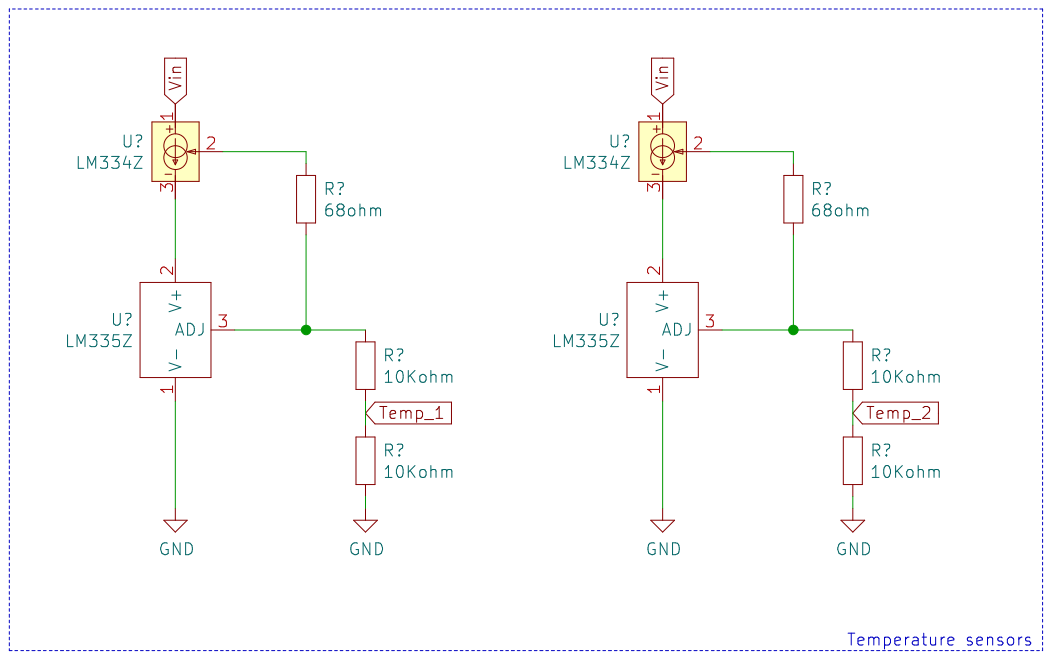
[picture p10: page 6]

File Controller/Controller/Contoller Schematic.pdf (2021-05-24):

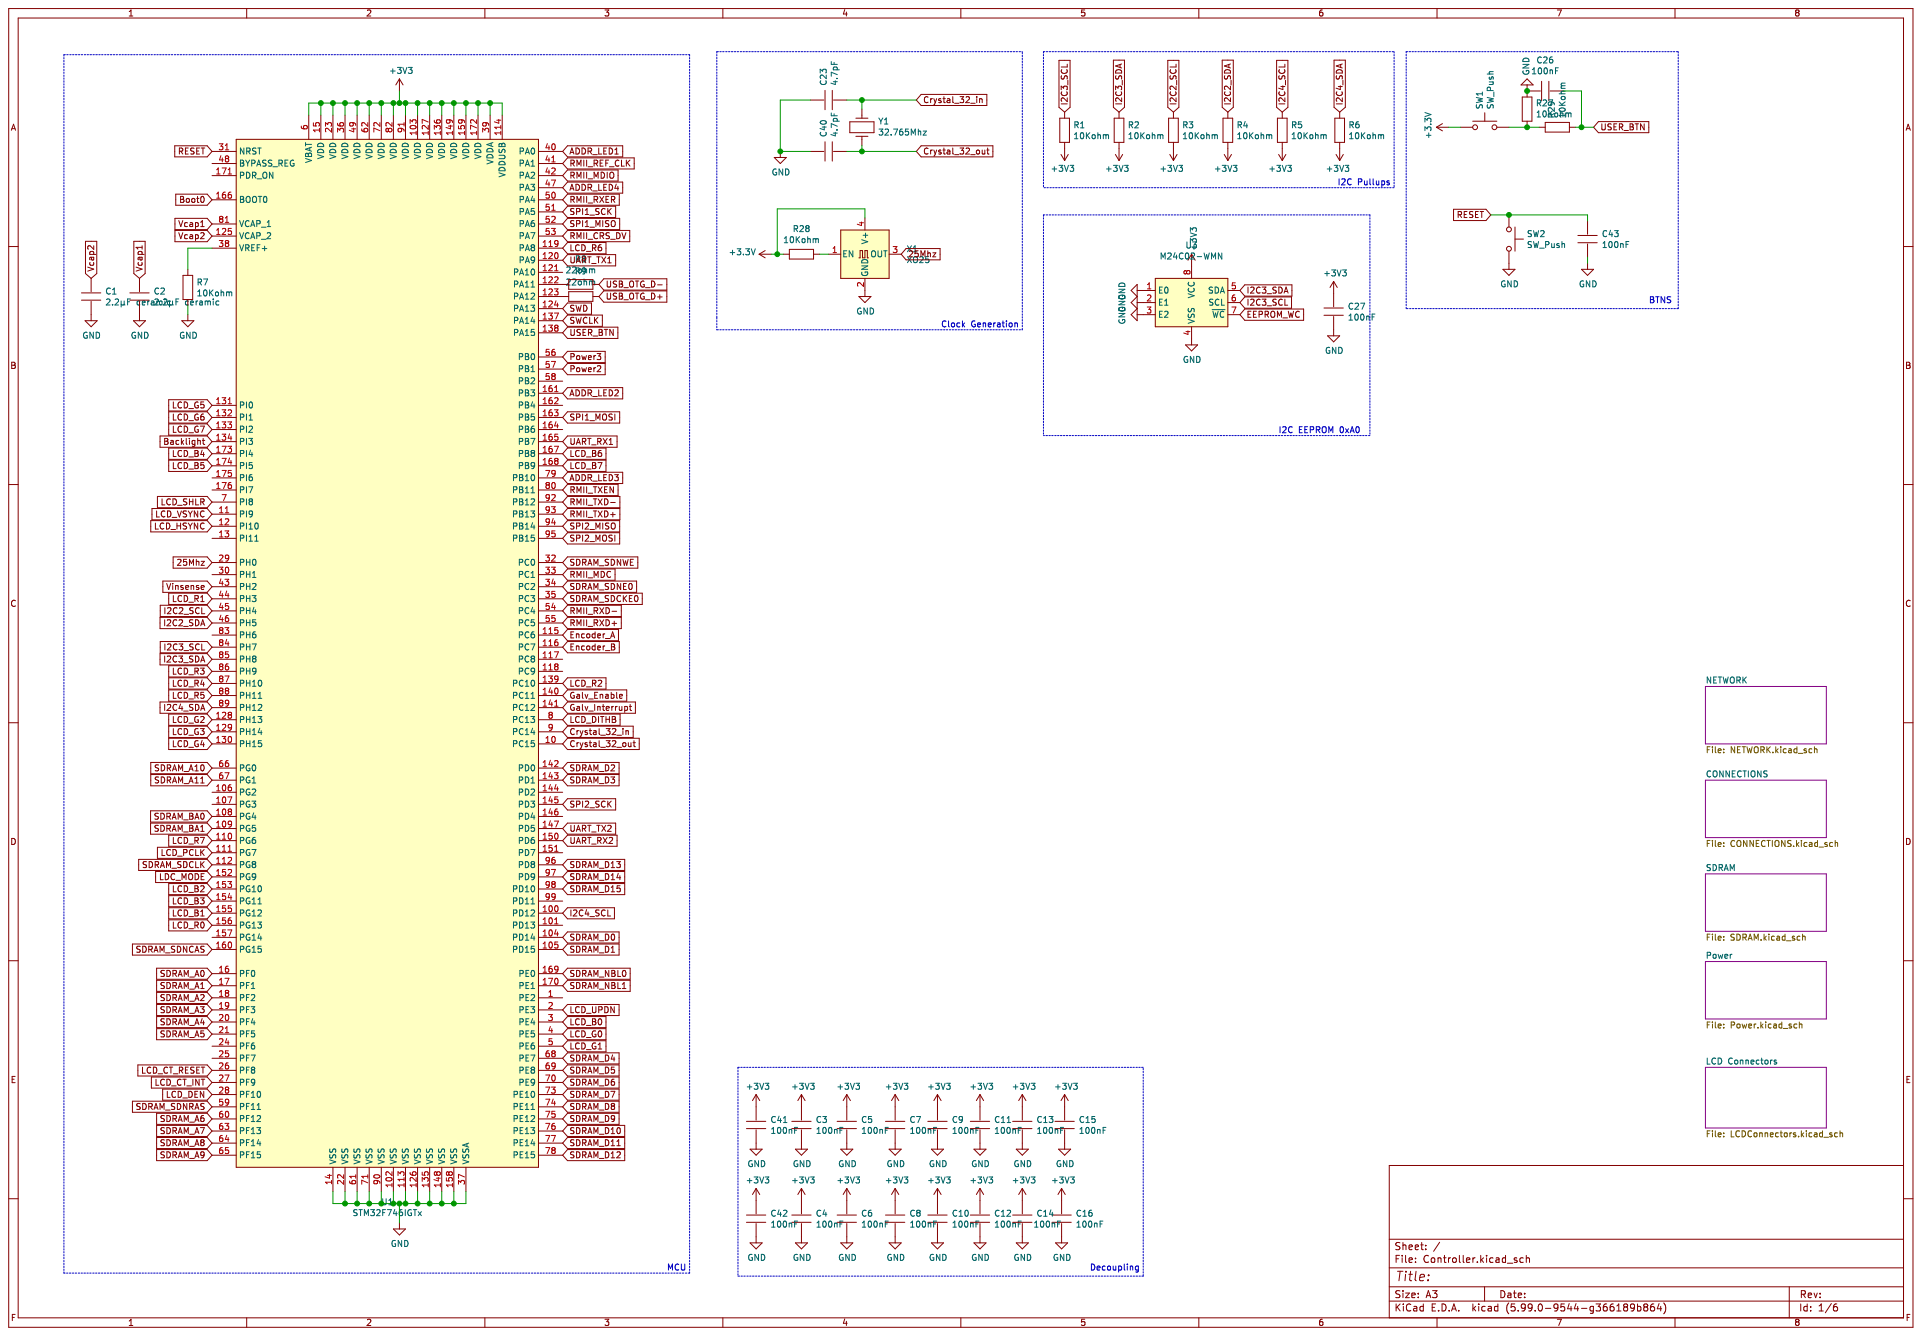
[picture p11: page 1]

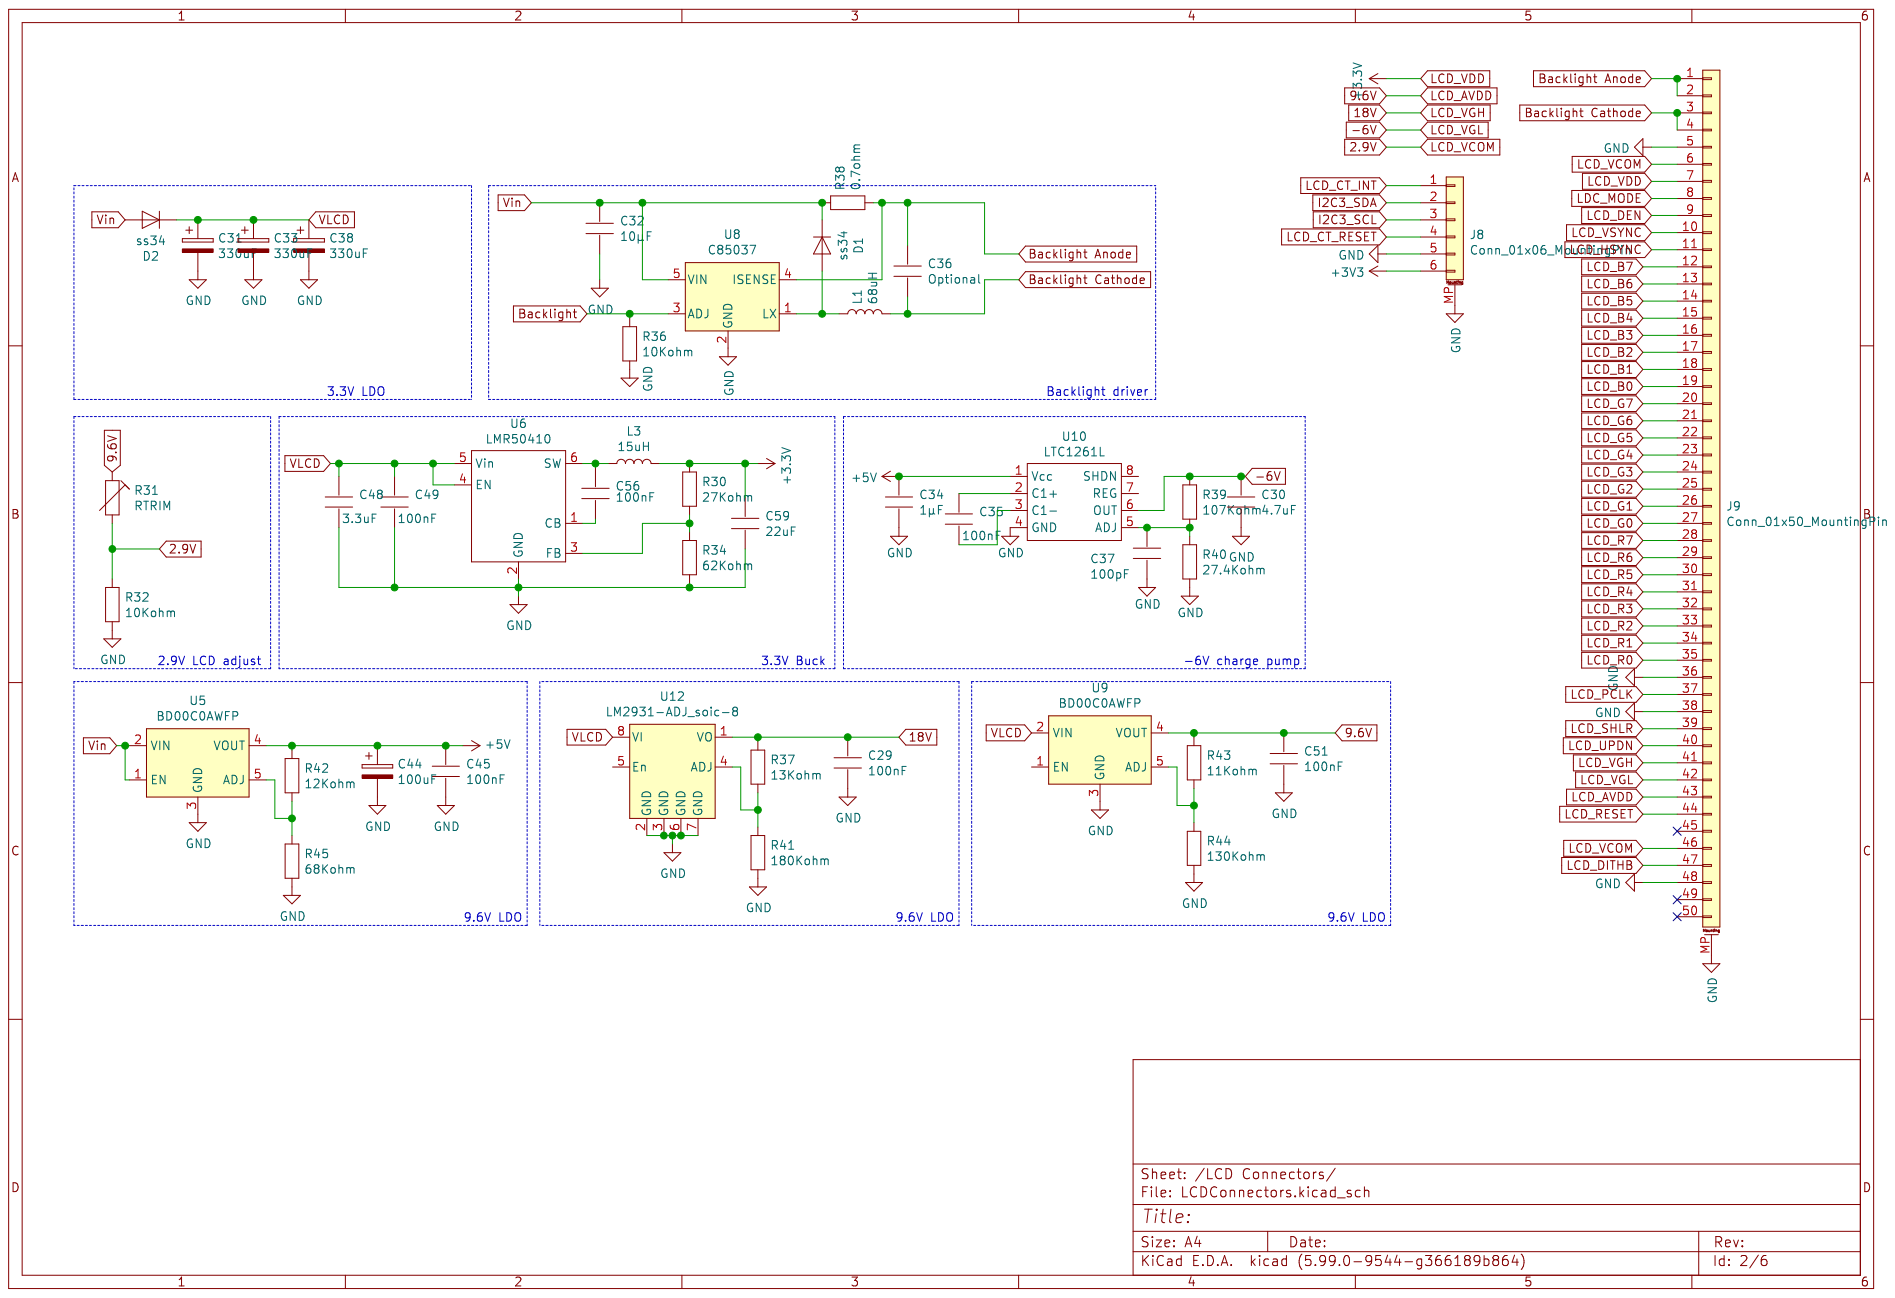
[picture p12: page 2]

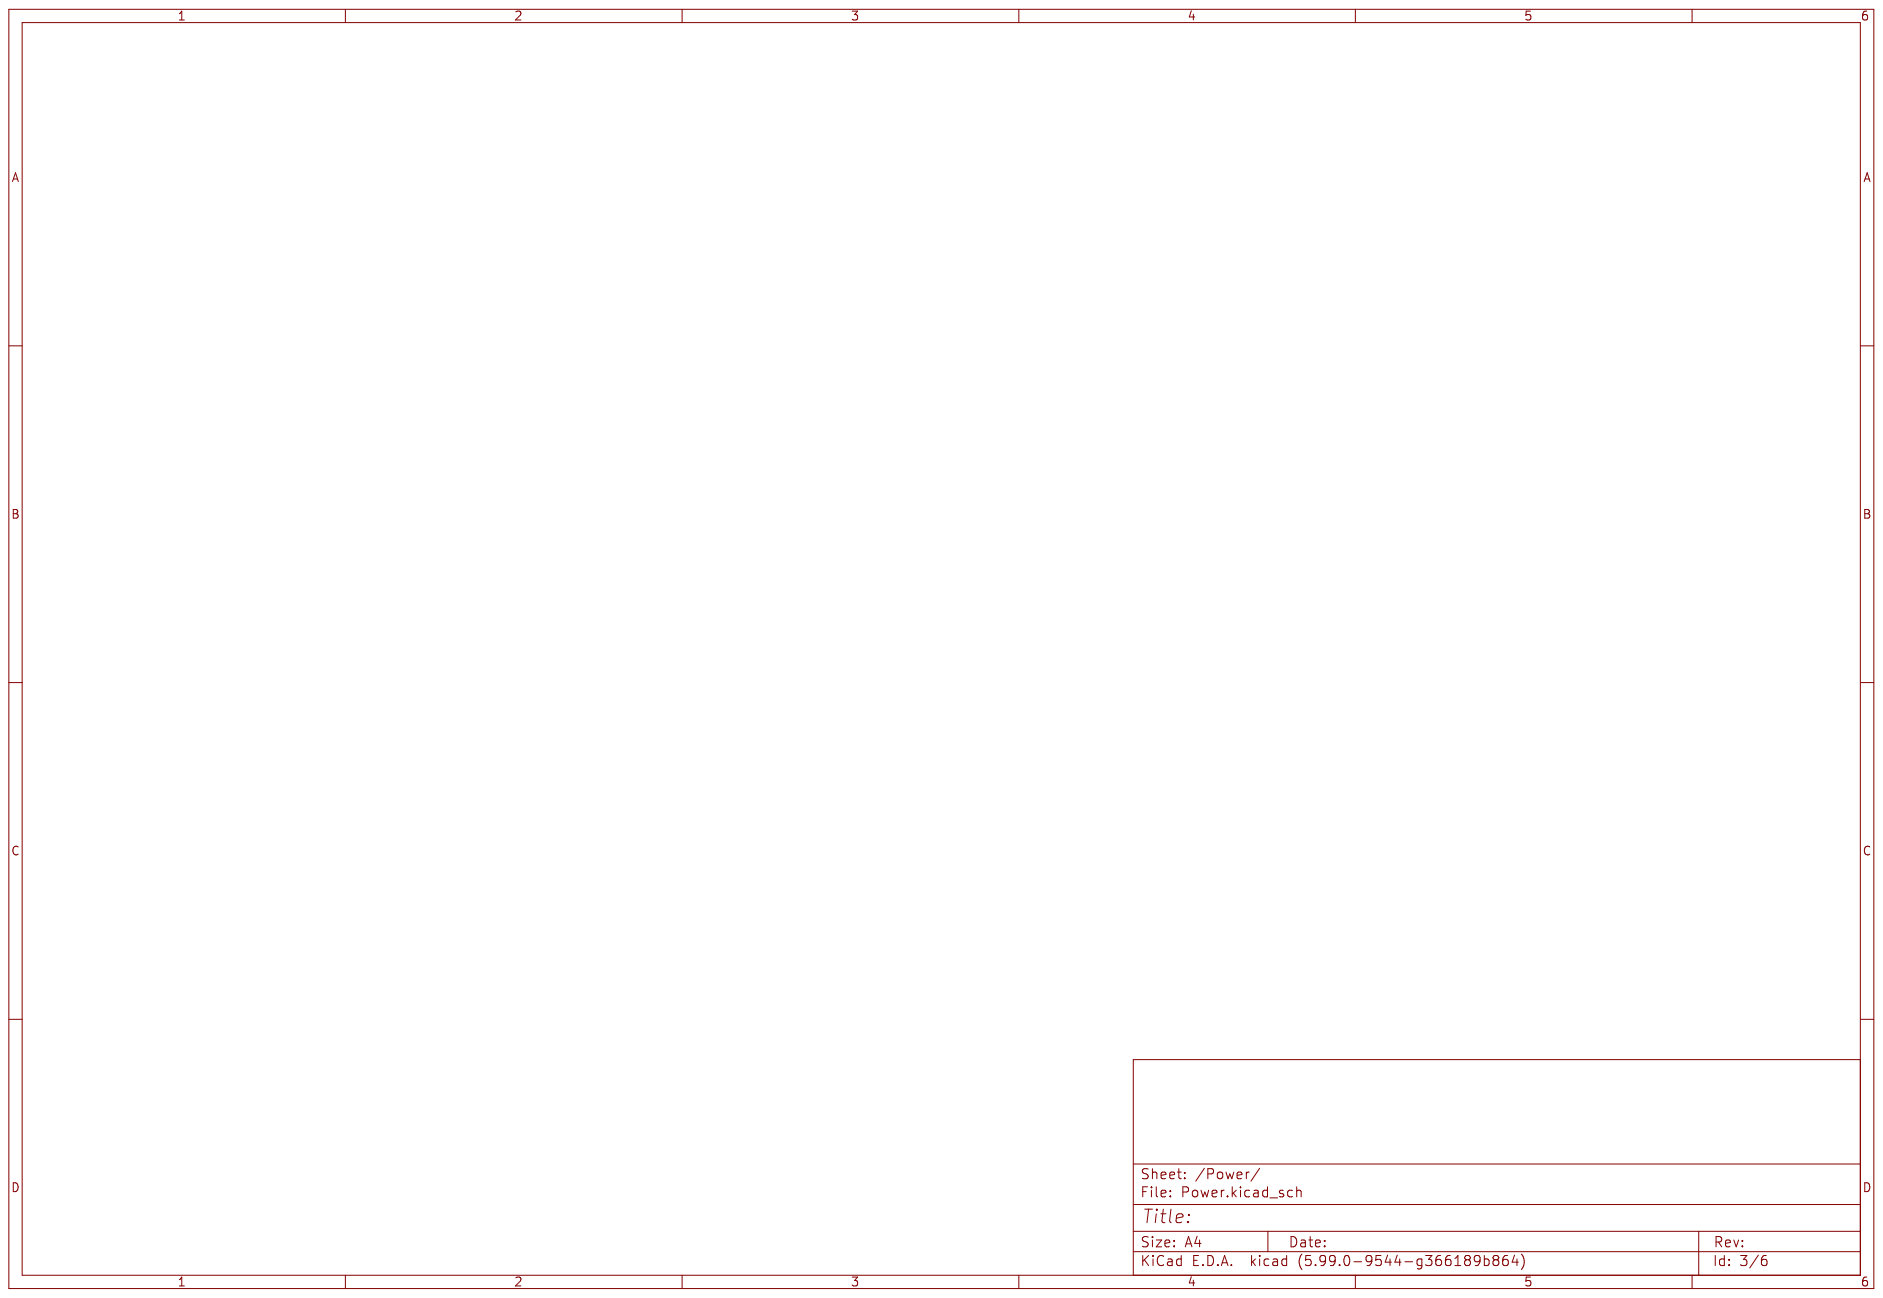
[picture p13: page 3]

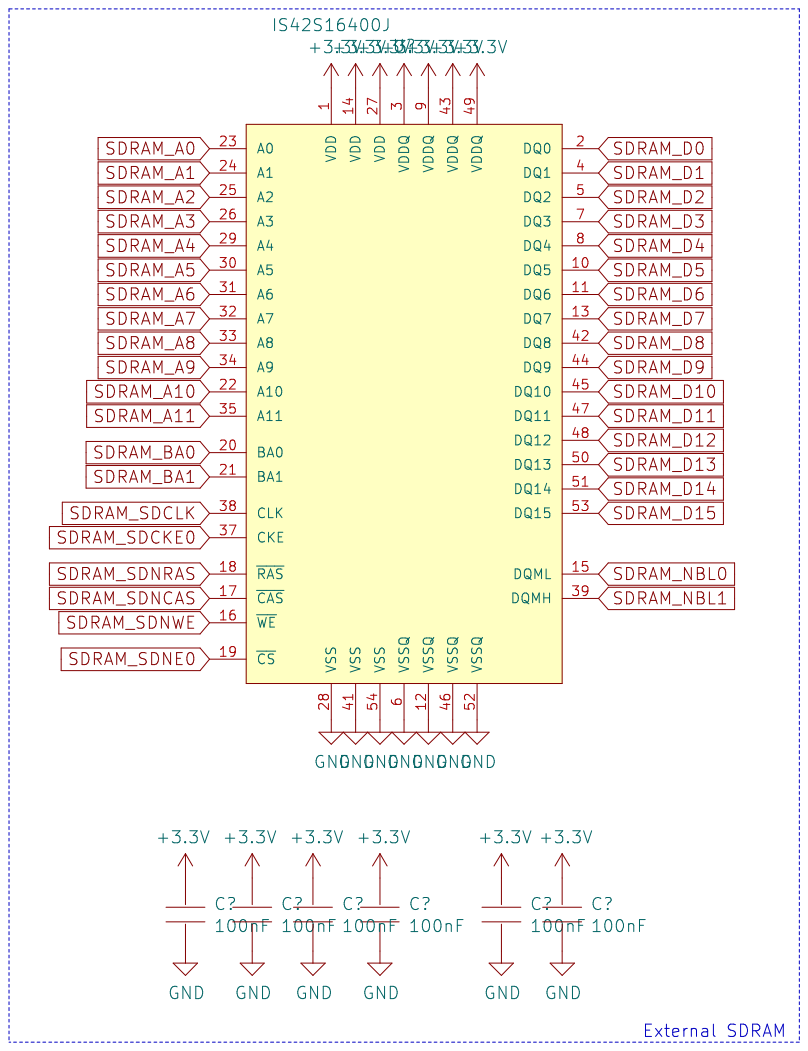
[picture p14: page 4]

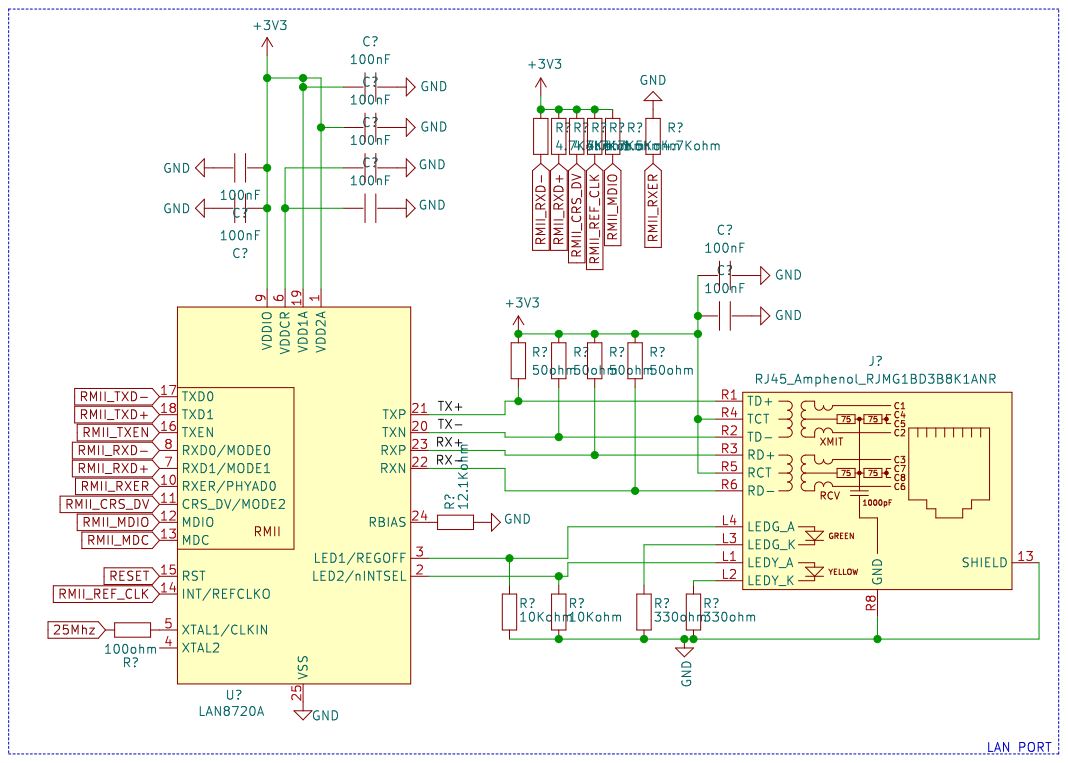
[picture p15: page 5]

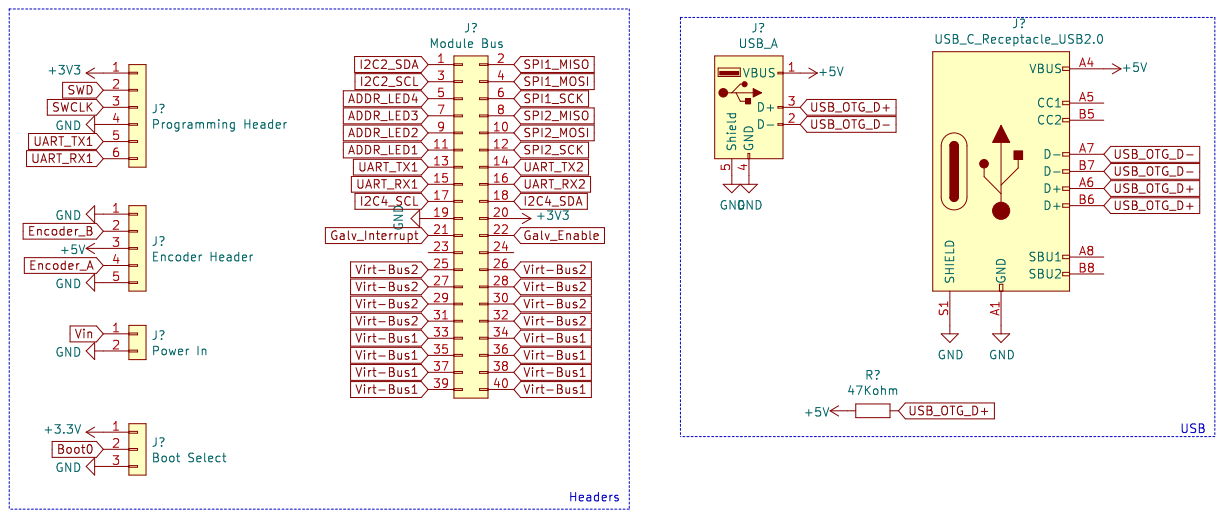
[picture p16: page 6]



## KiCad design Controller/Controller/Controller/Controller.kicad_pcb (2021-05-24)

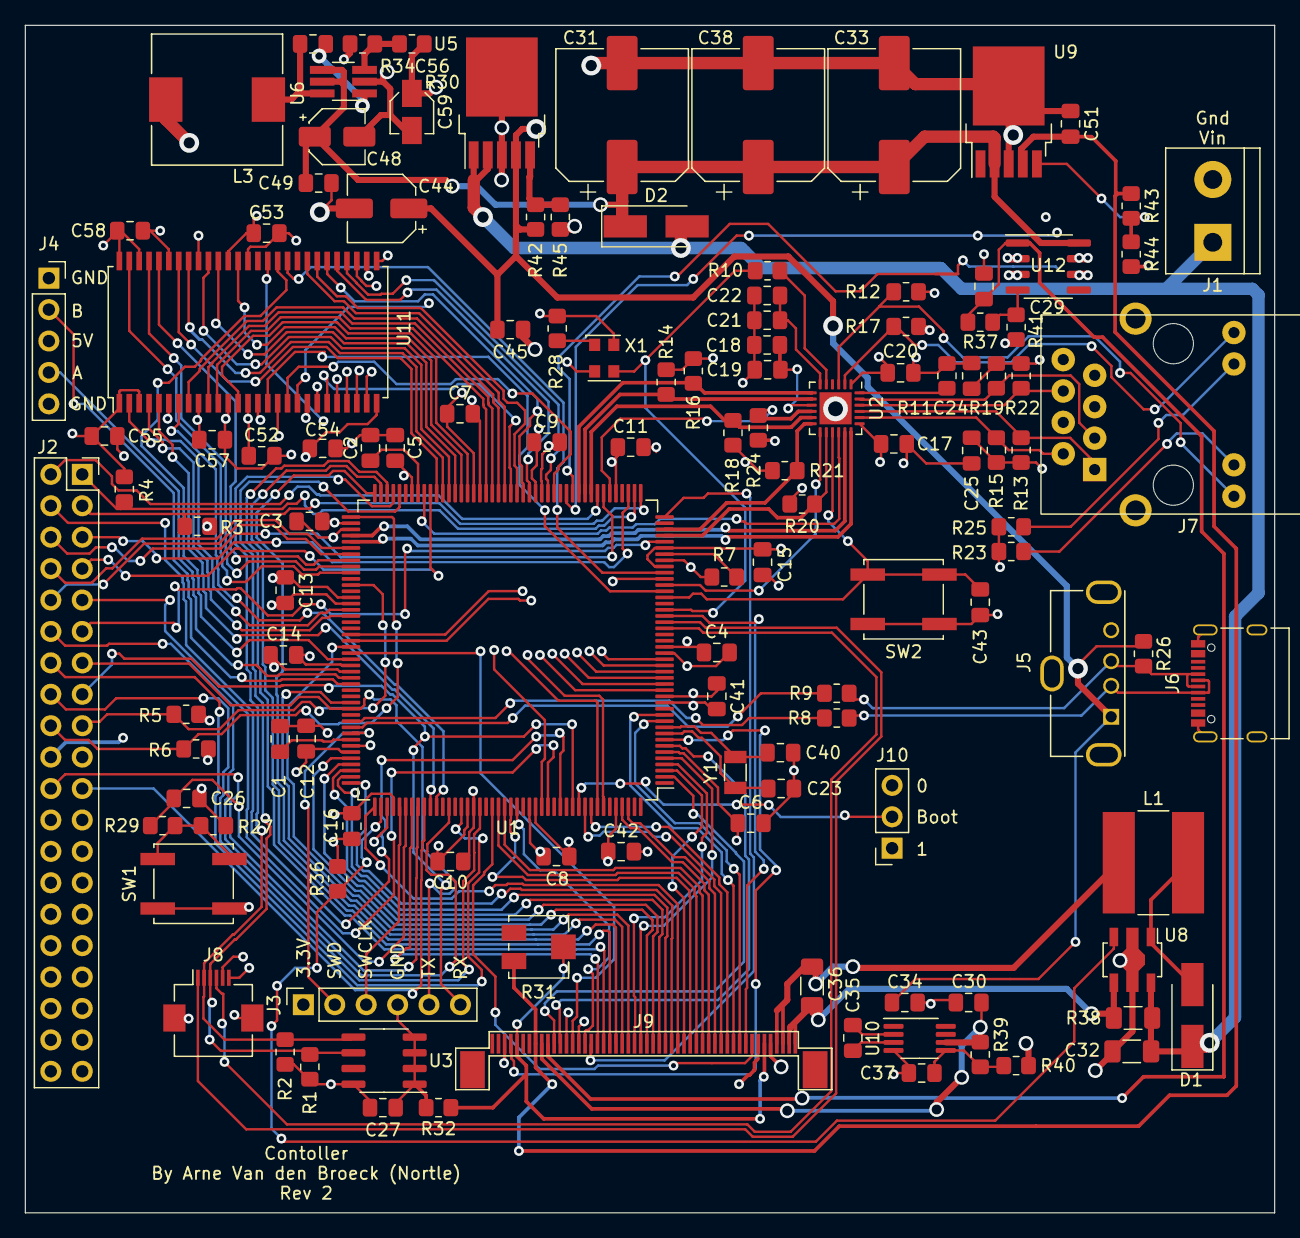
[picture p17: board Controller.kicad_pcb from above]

Board: 4 copper layers, 101.0 x 96.0 mm, 125 parts (0 on the bottom side), 158 nets.

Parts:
C1, C2: 2.2µF ceramic; C_0805_2012Metric_Pad1.18x1.45mm_HandSolder
C3, C4, C5, C6, C7, C8, C9, C10, C11, C12, C13, C14, C15, C16, C17, C18, C19, C20, C21, C22, C24, C25, C26, C27, C29, C35, C41, C42, C43, C45, C49, C51, C52, C53, C54, C55, C56, C57, C58: 100nF; C_0805_2012Metric_Pad1.18x1.45mm_HandSolder
C23, C40: 4.7pF; C_0805_2012Metric_Pad1.18x1.45mm_HandSolder
C30: 4.7uF; C_0805_2012Metric_Pad1.18x1.45mm_HandSolder
C31, C33, C38: 330uF; CP_Elec_10x10.5
C32: 10µF; C_1206_3216Metric_Pad1.33x1.80mm_HandSolder
C34: 1µF; C_0805_2012Metric_Pad1.18x1.45mm_HandSolder
C36: Optional; C_1206_3216Metric_Pad1.33x1.80mm_HandSolder
C37: 100pF; C_0805_2012Metric_Pad1.18x1.45mm_HandSolder
C44: 100uF; CP_Elec_5x5.4
C48: 3.3uF; CP_Elec_4x5.7
C59: 22uF; CP_Elec_3x5.3
D1, D2: ss34; D_SMA_Handsoldering
J1: Power In; TerminalBlock_bornier-2_P5.08mm
J2: Module Bus; PinSocket_2x20_P2.54mm_Vertical
J3: Programming Header; PinSocket_1x06_P2.54mm_Vertical
J4: Encoder Header; PinSocket_1x05_P2.54mm_Vertical
J5: USB_A; USB_A_Molex_105057_Vertical
J6: USB_C_Receptacle_USB2.0; USB_C_Receptacle_Palconn_UTC16-G
J7: RJ45_Amphenol_RJMG1BD3B8K1ANR; HR913550A
J8: Conn_01x06_MountingPin; Hirose_FH12-6S-0.5SH_1x06-1MP_P0.50mm_Horizontal
J9: Conn_01x50_MountingPin; FPC_50
J10: Boot Select; PinSocket_1x03_P2.54mm_Vertical
L1: 68uH; L_Bourns-SRN8040_8x8.15mm
L3: 15uH; L_10.4x10.4_H4.8
R1, R2, R3, R4, R5, R6, R7, R12, R17, R27, R28, R29, R32, R36: 10Kohm; R_0805_2012Metric_Pad1.20x1.40mm_HandSolder
R8, R9: 22ohm; R_0805_2012Metric_Pad1.20x1.40mm_HandSolder
R10: 100ohm; R_0805_2012Metric_Pad1.20x1.40mm_HandSolder
R11: 12.1Kohm; R_0805_2012Metric_Pad1.20x1.40mm_HandSolder
R13, R15, R19, R22: 50ohm; R_0805_2012Metric_Pad1.20x1.40mm_HandSolder
R14, R16, R18, R20, R24: 4.7Kohm; R_0805_2012Metric_Pad1.20x1.40mm_HandSolder
R21: 1.5Kohm; R_0805_2012Metric_Pad1.20x1.40mm_HandSolder
R23, R25: 330ohm; R_0805_2012Metric_Pad1.20x1.40mm_HandSolder
R26: 47Kohm; R_0805_2012Metric_Pad1.20x1.40mm_HandSolder
R30: 27Kohm; R_0805_2012Metric_Pad1.20x1.40mm_HandSolder
R31: RTRIM; Potentiometer_Bourns_3214J_Horizontal
R34: 62Kohm; R_0805_2012Metric_Pad1.20x1.40mm_HandSolder
R37: 13Kohm; R_0805_2012Metric_Pad1.20x1.40mm_HandSolder
R38: 0.7ohm; R_1206_3216Metric_Pad1.30x1.75mm_HandSolder
R39: 107Kohm; R_0805_2012Metric_Pad1.20x1.40mm_HandSolder
R40: 27.4Kohm; R_0805_2012Metric_Pad1.20x1.40mm_HandSolder
R41: 180Kohm; R_0805_2012Metric_Pad1.20x1.40mm_HandSolder
R42: 12Kohm; R_0805_2012Metric_Pad1.20x1.40mm_HandSolder
R43: 11Kohm; R_0805_2012Metric_Pad1.20x1.40mm_HandSolder
R44: 130Kohm; R_0805_2012Metric_Pad1.20x1.40mm_HandSolder
R45: 68Kohm; R_0805_2012Metric_Pad1.20x1.40mm_HandSolder
SW1, SW2: SW_Push; SW_Push_1P1T_NO_CK_KSC7xxJ
U1: STM32F746IGTx; LQFP-176_24x24mm_P0.5mm
U2: LAN8720A; QFN-24-1EP_4x4mm_P0.5mm_EP2.6x2.6mm
U3: M24C02-WMN; SOIC-8_3.9x4.9mm_P1.27mm
U5, U9: BD00C0AWFP; TO-252-5_TabPin3
U6: LMR50410; TSOT-23-6_HandSoldering
U8: C85037; SOT-89-5
U10: LTC1261L; MSOP-8_3x3mm_P0.65mm
U11: IS42S16400J; TSOP-II-54_22.2x10.16mm_P0.8mm
U12: LM2931-ADJ_soic-8; SOIC-8_3.9x4.9mm_P1.27mm
X1: XO25; Oscillator_SMD_EuroQuartz_XO32-4Pin_3.2x2.5mm
Y1: 32.765Mhz; Crystal_SMD_3215-2Pin_3.2x1.5mm

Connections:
2.9V: J9.6, J9.46, R31.2, R32.1
9.6V: C51.1, J9.43, R31.1, R43.1, U9.4 (VOUT)
18V: C29.1, J9.41, R37.1, U12.1 (VO)
25Mhz: R10.1, U1.29 (PH0), X1.3 (OUT)
+5V: C34.1, C44.1, C45.1, J4.3, J5.1 (VBUS), J6.A4 (VBUS), J6.A9 (VBUS), J6.B4 (VBUS), J6.B9 (VBUS), R26.1, R42.1, U5.4 (VOUT), U10.1 (Vcc)
-6V: C30.1, J9.42, R39.1, U10.6 (OUT)
/RX+: J7.R3 (RD+), R19.2, U2.23 (RXP)
/RX-: J7.R6 (RD-), R22.2, U2.22 (RXN)
/TX+: J7.R1 (TD+), R13.2, U2.21 (TXP)
/TX-: J7.R2 (TD-), R15.2, U2.20 (TXN)
ADDR_LED1: J2.11, U1.40 (PA0)
ADDR_LED2: J2.9, U1.161 (PB3)
ADDR_LED3: J2.7, U1.79 (PB10)
ADDR_LED4: J2.5, U1.47 (PA3)
Backlight: R36.1, U1.134 (PI3), U8.3 (ADJ)
Backlight Anode: C36.1, J9.1, J9.2, R38.2, U8.4 (ISENSE)
Backlight Cathode: C36.2, J9.3, J9.4, L1.2
Boot0: J10.2, U1.166 (BOOT0)
Crystal_32_in: C23.2, U1.9 (PC14), Y1.2
Crystal_32_out: C40.2, U1.10 (PC15), Y1.1
Encoder_A: J4.4, U1.115 (PC6)
Encoder_B: J4.2, U1.116 (PC7)
GND: C1.2, C2.2, C3.2, C4.2, C5.2, C6.2, C7.2, C8.2, C9.2, C10.2, C11.2, C12.2, C13.2, C14.2, C15.2, C16.2, C17.2, C18.2, C19.2, C20.2, C21.2, C22.2, C23.1, C24.2, C25.2, C26.1, C27.2, C29.2, C30.2, C31.2, C32.2, C33.2, C34.2, C37.2, C38.2, C40.1, C41.2, C42.2, C43.2, C44.2, C45.2, C48.2, C49.2, C51.2, C52.2, C53.2, C54.2, C55.2, C57.2, C58.2, C59.2, J1.2, J2.19, J3.4, J4.1, J4.5, J5.4 (GND), J5.5 (Shield), J6.A1 (GND), J6.A12 (GND), J6.B1 (GND), J6.B12 (GND), J6.S1 (SHIELD), J7.13 (SHIELD), J7.R8 (GND), J8.5, J8.MP (MountPin), J9.5, J9.36, J9.38, J9.48, J10.3, R7.2, R11.2, R12.2, R17.2, R23.2, R24.1, R25.2, R27.2, R32.2, R34.2, R36.2, R40.2, R41.2, R44.2, R45.2, SW2.2, U1.14 (VSS), U1.22 (VSS), U1.37 (VSSA), U1.61 (VSS), U1.71 (VSS), U1.90 (VSS), U1.102 (VSS), U1.113 (VSS), U1.126 (VSS), U1.135 (VSS), U1.148 (VSS), U1.158 (VSS), U2.25 (VSS), U3.1 (E0), U3.2 (E1), U3.3 (E2), U3.4 (VSS), U5.3 (GND), U6.2 (GND), U8.2 (GND), U9.3 (GND), U10.4 (GND), U11.6 (VSSQ), U11.12 (VSSQ), U11.28 (VSS), U11.41 (VSS), U11.46 (VSSQ), U11.52 (VSSQ), U11.54 (VSS), U12.2 (GND), U12.3 (GND), U12.6 (GND), U12.7 (GND), X1.2 (GND)
Galv_Enable: J2.22, U1.140 (PC11)
Galv_Interrupt: J2.21, U1.141 (PC12)
I2C2_SCL: J2.3, R3.1, U1.45 (PH4)
I2C2_SDA: J2.1, R4.1, U1.46 (PH5)
I2C3_SCL: J8.3, R1.1, U1.84 (PH7), U3.6 (SCL)
I2C3_SDA: J8.2, R2.1, U1.85 (PH8), U3.5 (SDA)
I2C4_SCL: J2.17, R5.1, U1.100 (PD12)
I2C4_SDA: J2.18, R6.1, U1.89 (PH12)
LCD_B0: J9.19, U1.3 (PE4)
LCD_B1: J9.18, U1.155 (PG12)
LCD_B2: J9.17, U1.153 (PG10)
LCD_B3: J9.16, U1.154 (PG11)
LCD_B4: J9.15, U1.173 (PI4)
LCD_B5: J9.14, U1.174 (PI5)
LCD_B6: J9.13, U1.167 (PB8)
LCD_B7: J9.12, U1.168 (PB9)
LCD_CT_INT: J8.1, U1.27 (PF9)
LCD_CT_RESET: J8.4, U1.26 (PF8)
LCD_DEN: J9.9, U1.28 (PF10)
LCD_DITHB: J9.47, U1.8 (PC13)
LCD_G0: J9.27, U1.4 (PE5)
LCD_G1: J9.26, U1.5 (PE6)
LCD_G2: J9.25, U1.128 (PH13)
LCD_G3: J9.24, U1.129 (PH14)
LCD_G4: J9.23, U1.130 (PH15)
LCD_G5: J9.22, U1.131 (PI0)
LCD_G6: J9.21, U1.132 (PI1)
LCD_G7: J9.20, U1.133 (PI2)
LCD_HSYNC: J9.11, U1.12 (PI10)
LCD_PCLK: J9.37, U1.111 (PG7)
LCD_R0: J9.35, U1.156 (PG13)
LCD_R1: J9.34, U1.44 (PH3)
LCD_R2: J9.33, U1.139 (PC10)
LCD_R3: J9.32, U1.86 (PH9)
LCD_R4: J9.31, U1.87 (PH10)
LCD_R5: J9.30, U1.88 (PH11)
LCD_R6: J9.29, U1.119 (PA8)
LCD_R7: J9.28, U1.110 (PG6)
LCD_SHLR: J9.39, U1.7 (PI8)
LCD_UPDN: J9.40, U1.2 (PE3)
LCD_VDD: C3.1, C4.1, C5.1, C6.1, C7.1, C8.1, C9.1, C10.1, C11.1, C12.1, C13.1, C14.1, C15.1, C16.1, C17.1, C18.1, C19.1, C20.1, C24.1, C25.1, C27.1, C41.1, C42.1, C52.1, C53.1, C54.1, C55.1, C57.1, C58.1, C59.1, J2.20, J3.1, J7.R4 (TCT), J7.R5 (RCT), J8.6, J9.7, J10.1, L3.2, R1.2, R2.2, R3.2, R4.2, R5.2, R6.2, R13.1, R14.1, R15.1, R16.1, R18.1, R19.1, R20.1, R21.1, R22.1, R28.1, R30.1, SW1.1, U1.6 (VBAT), U1.15 (VDD), U1.23 (VDD), U1.36 (VDD), U1.39 (VDDA), U1.49 (VDD), U1.62 (VDD), U1.72 (VDD), U1.82 (VDD), U1.91 (VDD), U1.103 (VDD), U1.114 (VDDUSB), U1.127 (VDD), U1.136 (VDD), U1.149 (VDD), U1.159 (VDD), U1.172 (VDD), U2.1 (VDD2A), U2.9 (VDDIO), U2.19 (VDD1A), U3.8 (VCC), U11.1 (VDD), U11.3 (VDDQ), U11.9 (VDDQ), U11.14 (VDD), U11.27 (VDD), U11.43 (VDDQ), U11.49 (VDDQ), X1.4 (V+)
LCD_VSYNC: J9.10, U1.11 (PI9)
LDC_MODE: J9.8, U1.152 (PG9)
unnamed: C21.1, C22.1, U2.6 (VDDCR)
unnamed: C35.1, U10.2 (C1+)
unnamed: C35.2, U10.3 (C1-)
unnamed: C37.1, R39.2, R40.1, U10.5 (ADJ)
unnamed: C56.1, L3.1, U6.6 (SW)
unnamed: C56.2, U6.1 (CB)
unnamed: D1.2 (A), L1.1, U8.1 (LX)
unnamed: J7.L1 (LEDY_A), R17.1, U2.2 (LED2/nINTSEL)
unnamed: J7.L2 (LEDY_K), R25.1
unnamed: J7.L3 (LEDG_K), R23.1
unnamed: J7.L4 (LEDG_A), R12.1, U2.3 (LED1/REGOFF)
unnamed: R7.1, U1.38 (VREF+)
unnamed: R8.1, U1.122 (PA11)
unnamed: R9.1, U1.123 (PA12)
unnamed: R10.2, U2.5 (XTAL1/CLKIN)
unnamed: R11.1, U2.24 (RBIAS)
unnamed: R27.1, R29.2, SW1.2
unnamed: R28.2, X1.1 (EN)
unnamed: R30.2, R34.1, U6.3 (FB)
unnamed: R37.2, R41.1, U12.4 (ADJ)
unnamed: R42.2, R45.1, U5.5 (ADJ)
unnamed: R43.2, R44.1, U9.5 (ADJ)
RESET: C43.1, SW2.1, U1.31 (NRST), U2.15 (RST)
RMII_CRS_DV: R18.2, U1.53 (PA7), U2.11 (CRS_DV/MODE2)
RMII_MDC: U1.33 (PC1), U2.13 (MDC)
RMII_MDIO: R21.2, U1.42 (PA2), U2.12 (MDIO)
RMII_REF_CLK: R20.2, U1.41 (PA1), U2.14 (INT/REFCLKO)
RMII_RXD+: R16.2, U1.55 (PC5), U2.7 (RXD1/MODE1)
RMII_RXD-: R14.2, U1.54 (PC4), U2.8 (RXD0/MODE0)
RMII_RXER: R24.2, U1.50 (PA4), U2.10 (RXER/PHYAD0)
RMII_TXD+: U1.93 (PB13), U2.18 (TXD1)
RMII_TXD-: U1.92 (PB12), U2.17 (TXD0)
RMII_TXEN: U1.80 (PB11), U2.16 (TXEN)
SDRAM_A0: U1.16 (PF0), U11.23 (A0)
SDRAM_A1: U1.17 (PF1), U11.24 (A1)
SDRAM_A2: U1.18 (PF2), U11.25 (A2)
SDRAM_A3: U1.19 (PF3), U11.26 (A3)
SDRAM_A4: U1.20 (PF4), U11.29 (A4)
SDRAM_A5: U1.21 (PF5), U11.30 (A5)
SDRAM_A6: U1.60 (PF12), U11.31 (A6)
SDRAM_A7: U1.63 (PF13), U11.32 (A7)
SDRAM_A8: U1.64 (PF14), U11.33 (A8)
SDRAM_A9: U1.65 (PF15), U11.34 (A9)
SDRAM_A10: U1.66 (PG0), U11.22 (A10)
SDRAM_A11: U1.67 (PG1), U11.35 (A11)
SDRAM_BA0: U1.108 (PG4), U11.20 (BA0)
SDRAM_BA1: U1.109 (PG5), U11.21 (BA1)
SDRAM_D0: U1.104 (PD14), U11.2 (DQ0)
SDRAM_D1: U1.105 (PD15), U11.4 (DQ1)
SDRAM_D2: U1.142 (PD0), U11.5 (DQ2)
SDRAM_D3: U1.143 (PD1), U11.7 (DQ3)
SDRAM_D4: U1.68 (PE7), U11.8 (DQ4)
SDRAM_D5: U1.69 (PE8), U11.10 (DQ5)
SDRAM_D6: U1.70 (PE9), U11.11 (DQ6)
SDRAM_D7: U1.73 (PE10), U11.13 (DQ7)
SDRAM_D8: U1.74 (PE11), U11.42 (DQ8)
SDRAM_D9: U1.75 (PE12), U11.44 (DQ9)
SDRAM_D10: U1.76 (PE13), U11.45 (DQ10)
SDRAM_D11: U1.77 (PE14), U11.47 (DQ11)
SDRAM_D12: U1.78 (PE15), U11.48 (DQ12)
SDRAM_D13: U1.96 (PD8), U11.50 (DQ13)
SDRAM_D14: U1.97 (PD9), U11.51 (DQ14)
SDRAM_D15: U1.98 (PD10), U11.53 (DQ15)
SDRAM_NBL0: U1.169 (PE0), U11.15 (DQML)
SDRAM_NBL1: U1.170 (PE1), U11.39 (DQMH)
SDRAM_SDCKE0: U1.35 (PC3), U11.37 (CKE)
SDRAM_SDCLK: U1.112 (PG8), U11.38 (CLK)
SDRAM_SDNCAS: U1.160 (PG15), U11.17 (~CAS~)
SDRAM_SDNE0: U1.34 (PC2), U11.19 (~CS~)
SDRAM_SDNRAS: U1.59 (PF11), U11.18 (~RAS~)
SDRAM_SDNWE: U1.32 (PC0), U11.16 (~WE~)
SPI1_MISO: J2.2, U1.52 (PA6)
SPI1_MOSI: J2.4, U1.163 (PB5)
SPI1_SCK: J2.6, U1.51 (PA5)
SPI2_MISO: J2.8, U1.94 (PB14)
SPI2_MOSI: J2.10, U1.95 (PB15)
SPI2_SCK: J2.12, U1.145 (PD3)
SWCLK: J3.3, U1.137 (PA14)
SWD: J3.2, U1.124 (PA13)
UART_RX1: J2.15, J3.6, U1.165 (PB7)
UART_RX2: J2.16, U1.150 (PD6)
UART_TX1: J2.13, J3.5, U1.120 (PA9)
UART_TX2: J2.14, U1.147 (PD5)
USB_OTG_D+: J5.3 (D+), J6.A6 (D+), J6.B6 (D+), R9.2, R26.2
USB_OTG_D-: J5.2 (D-), J6.A7 (D-), J6.B7 (D-), R8.2
USER_BTN: C26.2, R29.1, U1.138 (PA15)
VLCD: C31.1, C33.1, C38.1, C48.1, C49.1, D2.1 (K), U6.4 (EN), U6.5 (Vin), U9.2 (VIN), U12.8 (VI)
Vcap1: C2.1, U1.81 (VCAP_1)
Vcap2: C1.1, U1.125 (VCAP_2)
Vin: C32.1, D1.1 (K), D2.2 (A), J1.1, R38.1, U5.1 (EN), U5.2 (VIN), U8.5 (VIN)
Virt-Bus1: J2.33, J2.34, J2.35, J2.36, J2.37, J2.38, J2.39, J2.40
Virt-Bus2: J2.25, J2.26, J2.27, J2.28, J2.29, J2.30, J2.31, J2.32

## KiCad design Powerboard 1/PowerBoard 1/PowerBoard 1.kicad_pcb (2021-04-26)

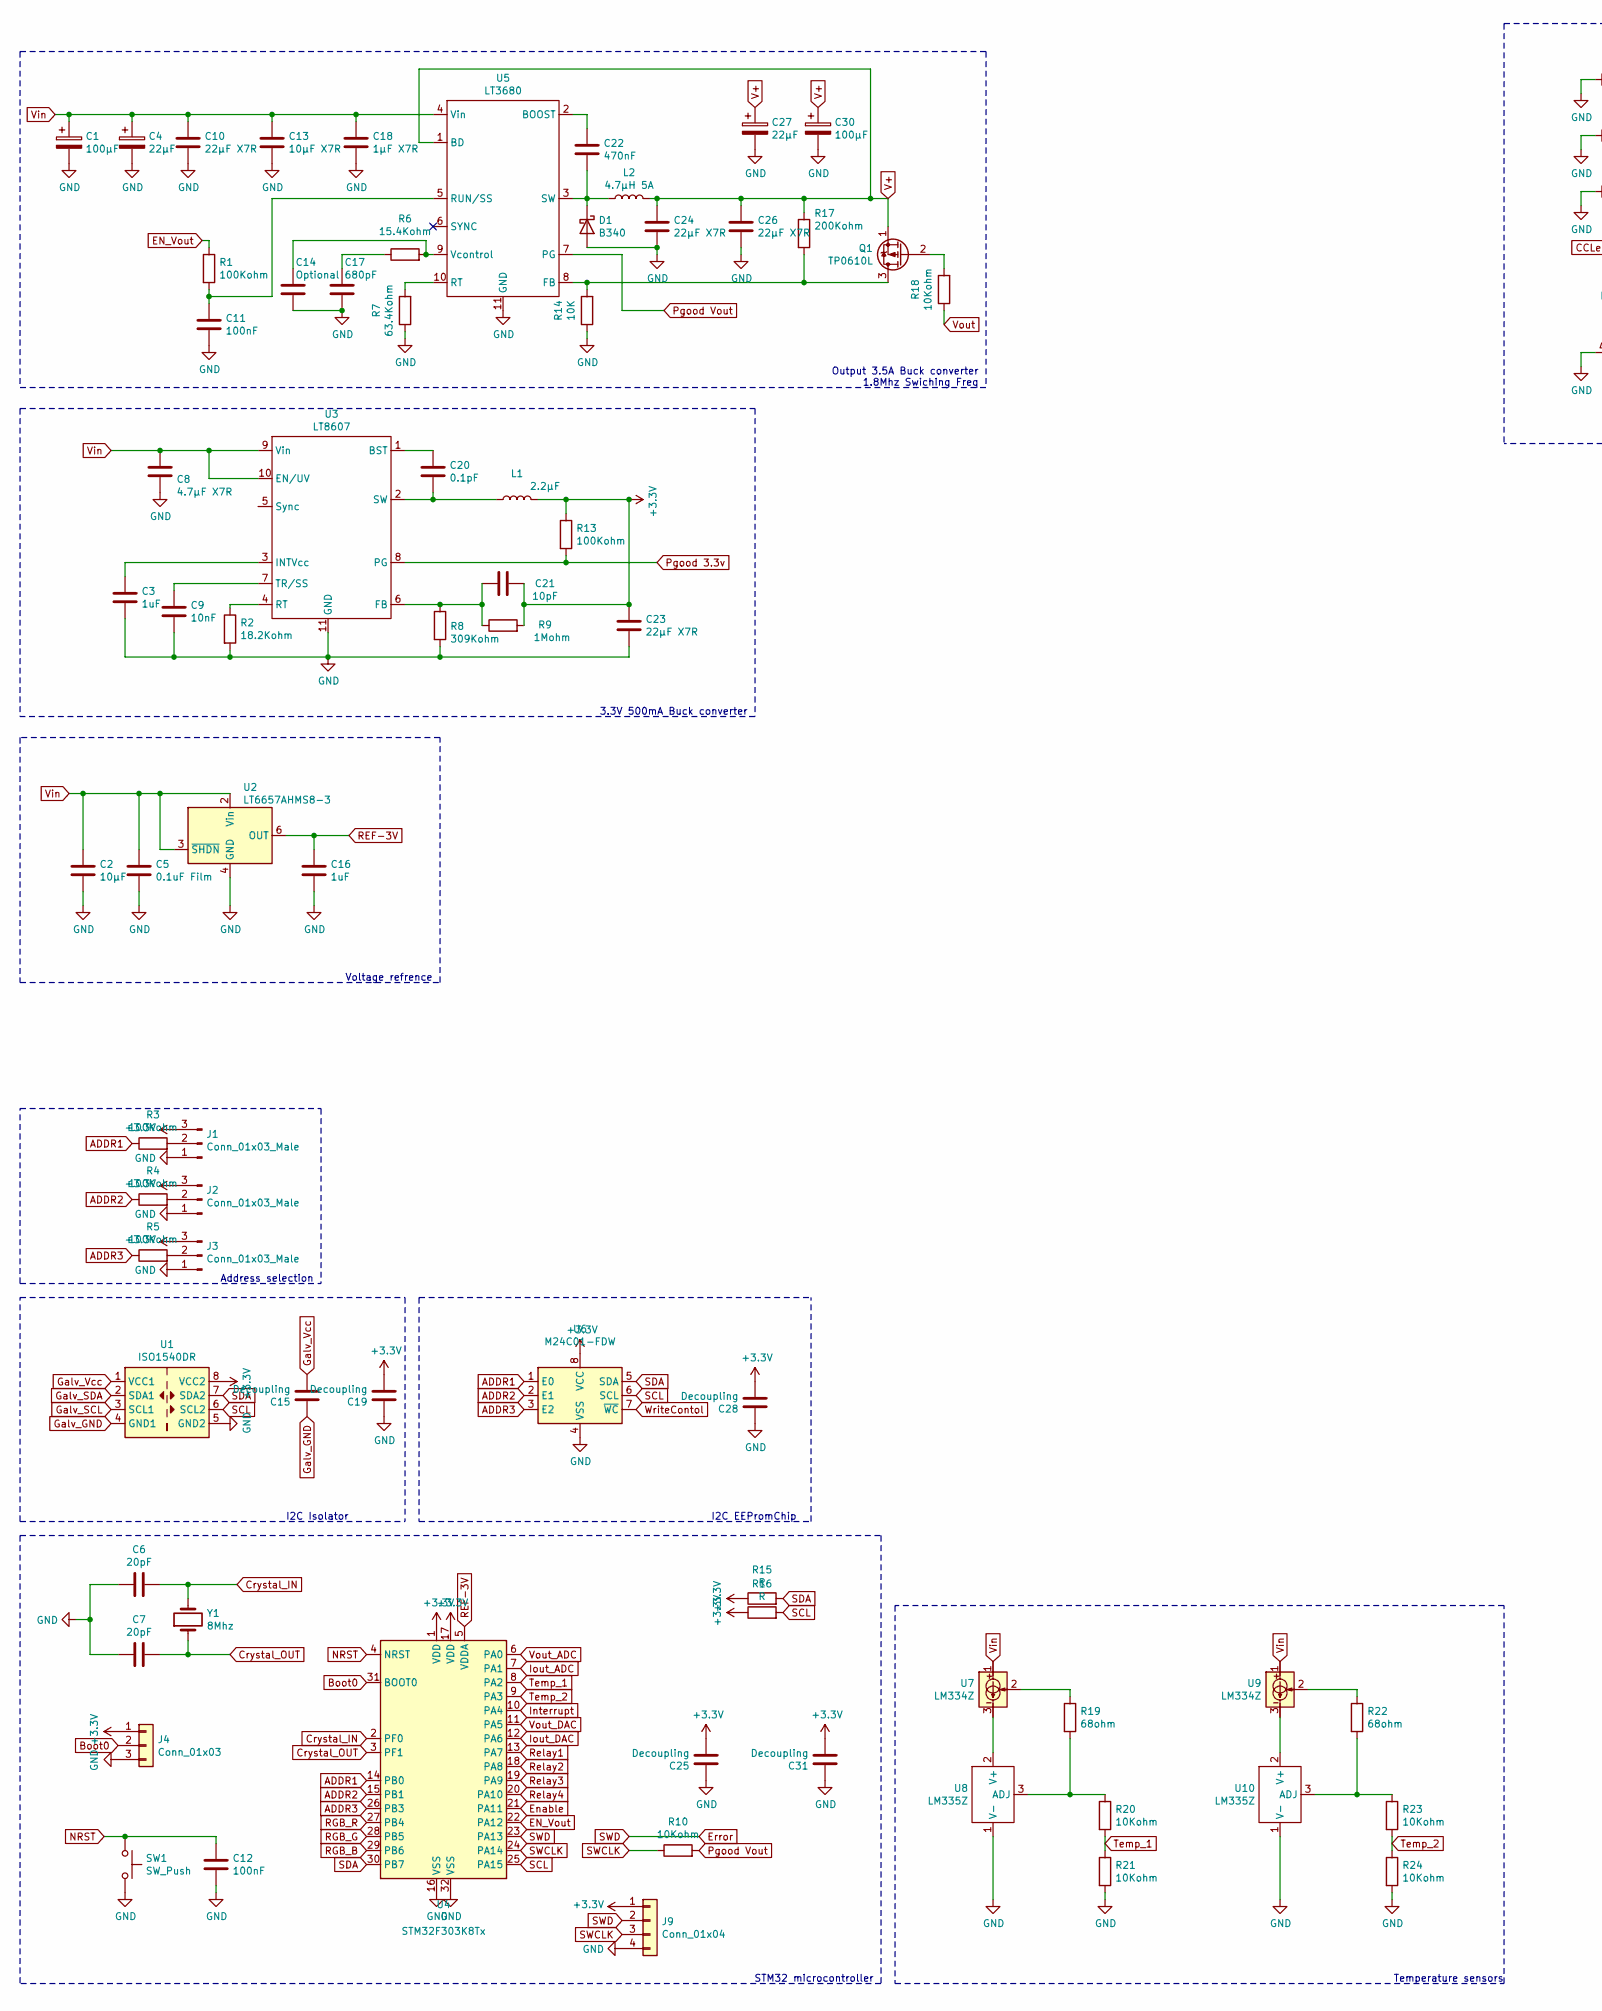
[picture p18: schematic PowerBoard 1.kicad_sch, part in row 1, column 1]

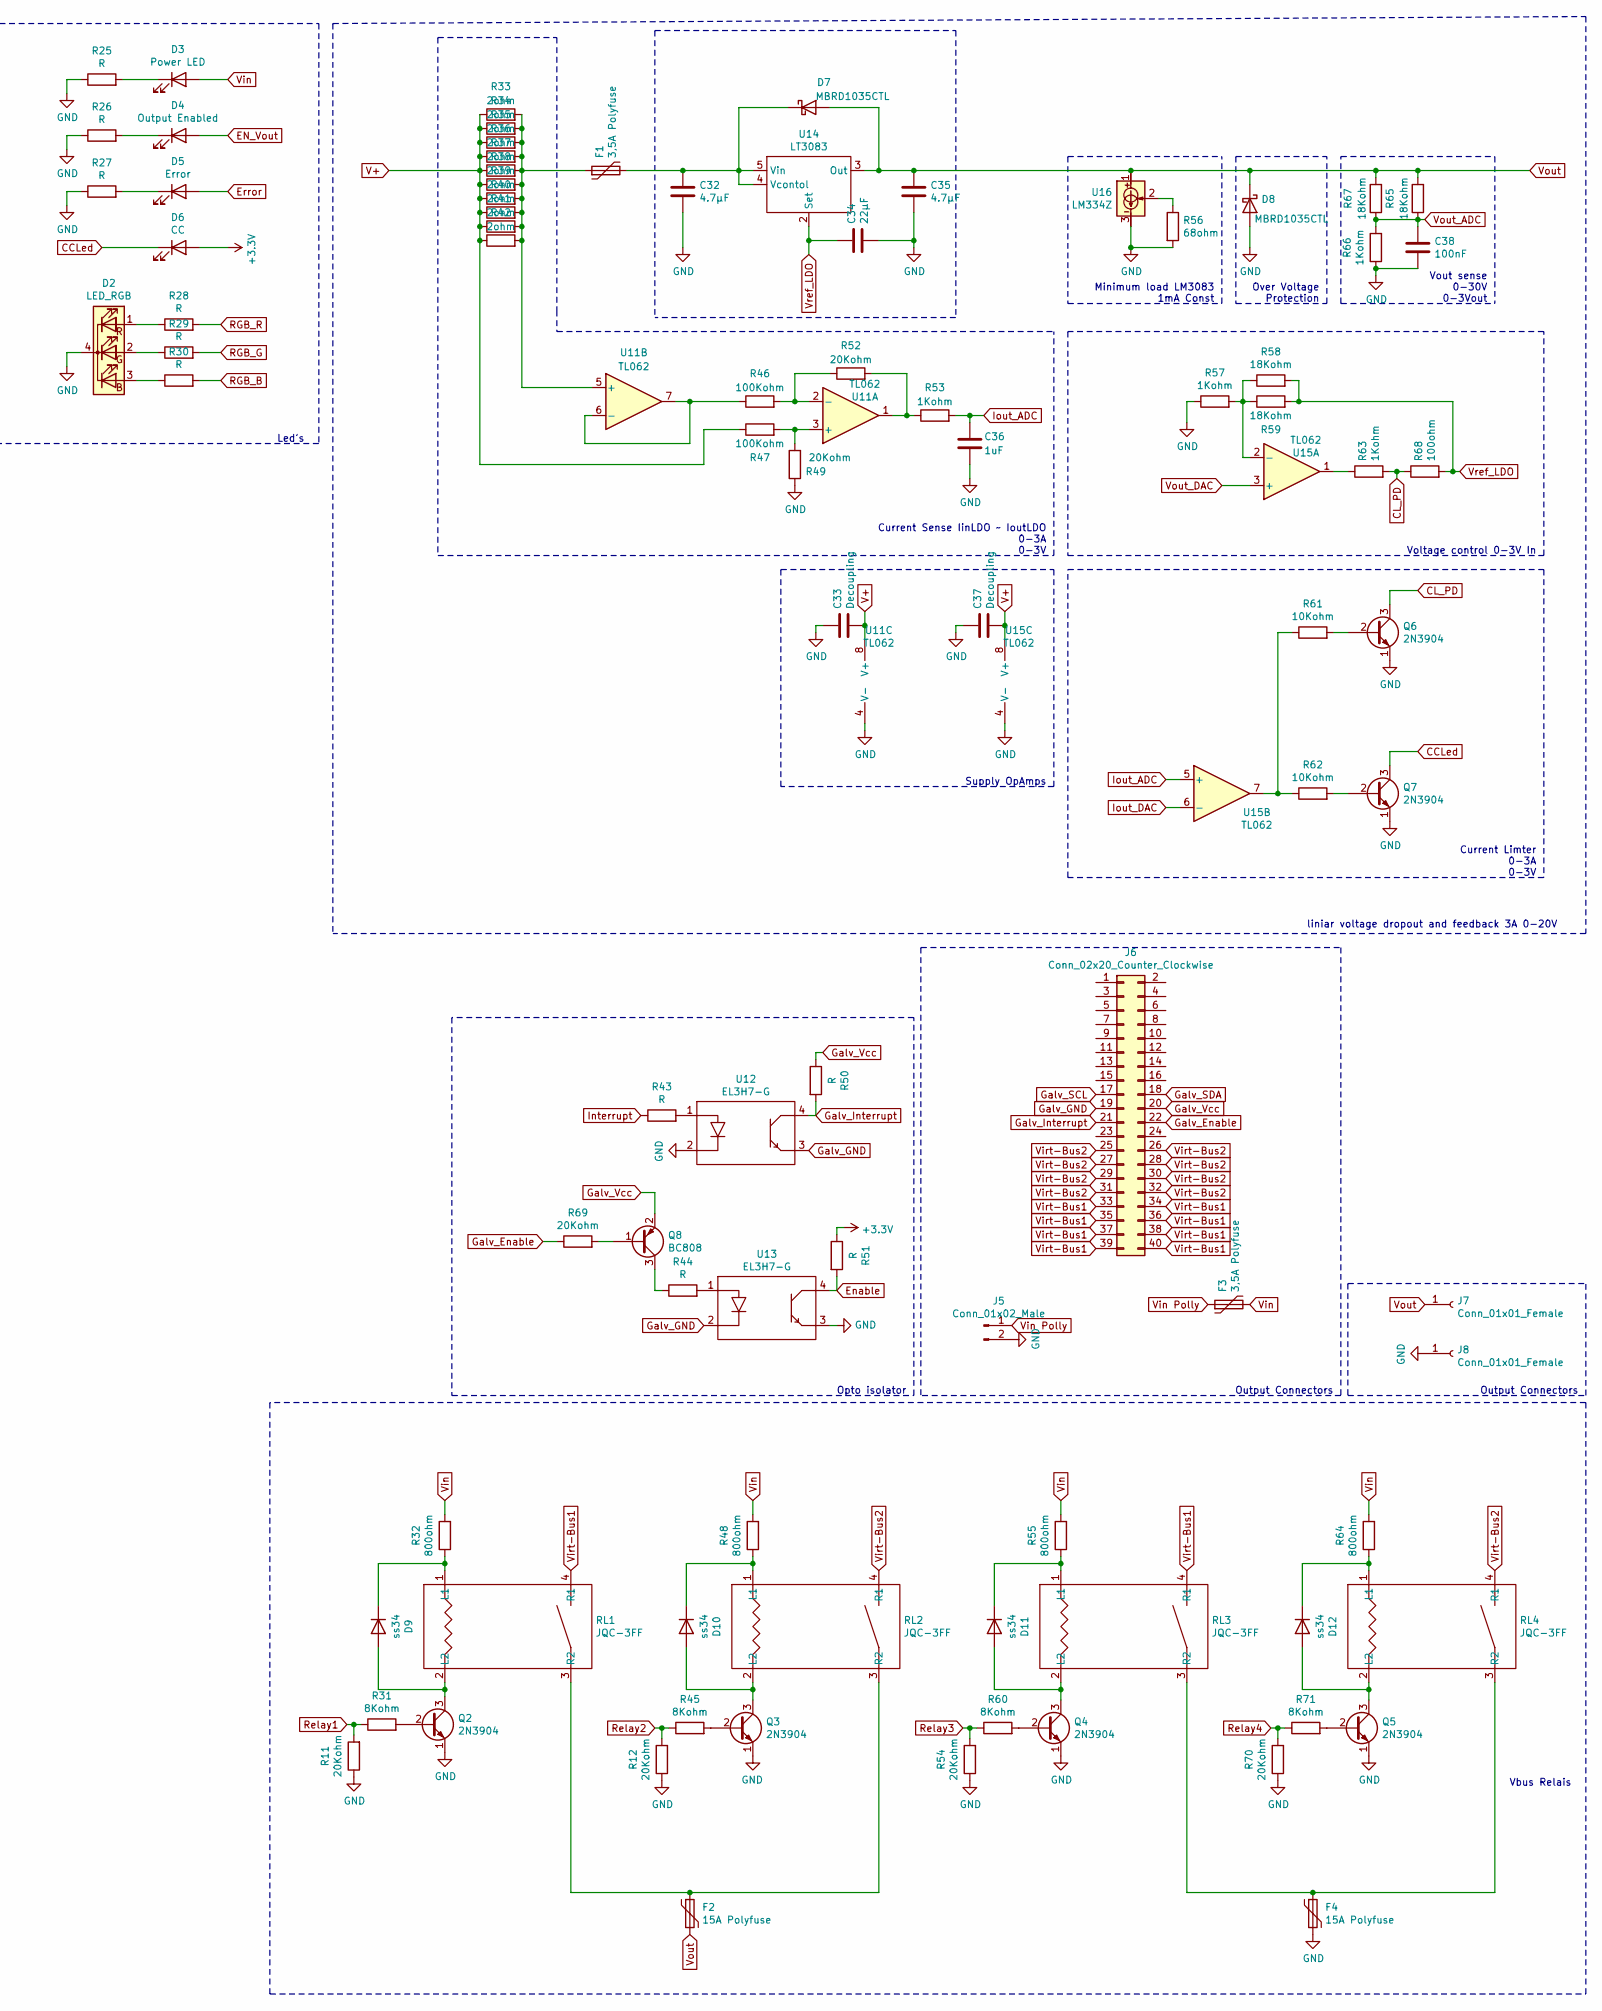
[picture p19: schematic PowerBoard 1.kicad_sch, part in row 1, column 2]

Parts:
C1, C30: 100µF; C_Elec_8x10.2
C2: 10µF; C_0805_2012Metric_Pad1.18x1.45mm_HandSolder
C3, C16, C36: 1uF; C_0805_2012Metric_Pad1.18x1.45mm_HandSolder
C4, C27: 22µF; C_Elec_6.3x5.4
C5: 0.1uF Film; C_0805_2012Metric_Pad1.18x1.45mm_HandSolder
C6, C7: 20pF; C_0805_2012Metric_Pad1.18x1.45mm_HandSolder
C8: 4.7µF X7R; C_1206_3216Metric_Pad1.33x1.80mm_HandSolder
C9: 10nF; C_0805_2012Metric_Pad1.18x1.45mm_HandSolder
C10, C23, C24, C26: 22µF X7R; C_2220_5650Metric_Pad1.97x5.40mm_HandSolder
C11, C12, C38: 100nF; C_0805_2012Metric_Pad1.18x1.45mm_HandSolder
C13: 10µF X7R; C_1206_3216Metric_Pad1.33x1.80mm_HandSolder
C14: Optional; C_0805_2012Metric_Pad1.18x1.45mm_HandSolder
C15, C19, C25, C28, C31, C33, C37: Decoupling; C_0805_2012Metric_Pad1.18x1.45mm_HandSolder
C17: 680pF; C_0805_2012Metric_Pad1.18x1.45mm_HandSolder
C18: 1µF X7R; C_0805_2012Metric_Pad1.18x1.45mm_HandSolder
C20: 0.1pF; C_0603_1608Metric_Pad1.08x0.95mm_HandSolder
C21: 10pF; C_0805_2012Metric_Pad1.18x1.45mm_HandSolder
C22: 470nF; C_0805_2012Metric_Pad1.18x1.45mm_HandSolder
C32, C35: 4.7µF; C_0805_2012Metric_Pad1.18x1.45mm_HandSolder
C34: 22µF; C_0805_2012Metric_Pad1.18x1.45mm_HandSolder
D1: B340; D_SMA_Handsoldering
D2: LED_RGB; LED_D5.0mm-4_RGB_Wide_Pins
D3: Power LED; LED_D5.0mm
D4: Output Enabled; LED_D5.0mm
D5: Error; LED_D5.0mm
D6: CC; LED_D5.0mm
D7, D8: MBRD1035CTL; TO-252-2
D9, D10, D11, D12: ss34; D_SMA_Handsoldering; LCSC C83961
F1, F3: 3,5A Polyfuse; Fuse_1206_3216Metric_Pad1.42x1.75mm_HandSolder
F2, F4: 15A Polyfuse; Fuse_1812_4532Metric_Pad1.30x3.40mm_HandSolder
J1, J2, J3: Conn_01x03_Male; PinSocket_1x03_P2.54mm_Vertical
J4: Conn_01x03; PinSocket_1x03_P2.54mm_Vertical
J5: Conn_01x02_Male; TerminalBlock_bornier-2_P5.08mm
J6: Conn_02x20_Counter_Clockwise; PinSocket_2x20_P2.54mm_Vertical
J7, J8: Conn_01x01_Female; SolderWirePad_1x01_SMD_5x10mm
J9: Conn_01x04; PinSocket_1x04_P2.54mm_Vertical
L1: 2.2µF; L_Wuerth_MAPI-3020
L2: 4.7µH 5A; L_7.3x7.3_H3.5
Q1: TP0610L; SOT-23
Q2, Q3, Q4, Q5, Q6, Q7: 2N3904; SOT-23
Q8: BC808; SOT-23
R1, R3, R4, R5, R13, R46, R47: 100Kohm; R_0805_2012Metric_Pad1.20x1.40mm_HandSolder
R2: 18.2Kohm; R_0805_2012Metric_Pad1.20x1.40mm_HandSolder
R6: 15.4Kohm; R_0805_2012Metric_Pad1.20x1.40mm_HandSolder
R7: 63.4Kohm; R_0805_2012Metric_Pad1.20x1.40mm_HandSolder
R8: 309Kohm; R_0805_2012Metric_Pad1.20x1.40mm_HandSolder
R9: 1Mohm; R_0805_2012Metric_Pad1.20x1.40mm_HandSolder
R10, R18, R20, R21, R23, R24, R61, R62: 10Kohm; R_0805_2012Metric_Pad1.20x1.40mm_HandSolder
R11, R12, R49, R52, R54, R69, R70: 20Kohm; R_0805_2012Metric_Pad1.20x1.40mm_HandSolder
R14: 10K; R_0805_2012Metric_Pad1.20x1.40mm_HandSolder
R15, R16, R25, R26, R27, R28, R29, R30, R43, R44, R50, R51: R; R_0805_2012Metric_Pad1.20x1.40mm_HandSolder
R17: 200Kohm; R_0805_2012Metric_Pad1.20x1.40mm_HandSolder
R19, R22, R56: 68ohm; R_0805_2012Metric_Pad1.20x1.40mm_HandSolder
R31, R45, R60, R71: 8Kohm; R_0805_2012Metric_Pad1.20x1.40mm_HandSolder
R32, R48, R55, R64: 800ohm; R_0805_2012Metric_Pad1.20x1.40mm_HandSolder
R33, R34, R35, R36, R37, R38, R39, R40, R41, R42: 2ohm; R_0805_2012Metric_Pad1.20x1.40mm_HandSolder
R53, R57, R63, R66: 1Kohm; R_0805_2012Metric_Pad1.20x1.40mm_HandSolder
R58, R59, R65, R67: 18Kohm; R_0805_2012Metric_Pad1.20x1.40mm_HandSolder
R68: 100ohm; R_0805_2012Metric_Pad1.20x1.40mm_HandSolder
RL1, RL2, RL3, RL4: JQC-3FF
SW1: SW_Push; SW_Push_1P1T_NO_CK_KSC7xxJ
U1: ISO1540DR; SOIC-8_3.9x4.9mm_P1.27mm
U2: LT6657AHMS8-3; MSOP-8_3x3mm_P0.65mm
U3: LT8607; MSOP-10_handsolder
U4: STM32F303K8Tx; LQFP-32_7x7mm_P0.8mm
U5: LT3680; MSOP-10_handsolder
U6: M24C01-FDW; TSSOP-8_4.4x3mm_P0.65mm
U7, U9, U16: LM334Z; TO-92_Inline
U8, U10: LM335Z; TO-92_Inline
U11, U15: TL062; SOIC-8_3.9x4.9mm_P1.27mm
U12, U13: EL3H7-G; SOP-4_4.4x2.6mm_P1.27mm
U14: LT3083; TO-220-5_Horizontal_TabDown
Y1: 8Mhz; Crystal_SMD_HC49-SD_HandSoldering

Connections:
+3V3: C19.1, C21.2, C23.1, C25.1, C28.1, C31.1, D6.2 (A), J1.3, J2.3, J3.3, J4.1, J9.1, L1.2, R9.2, R13.1, R15.1, R16.1, R51.1, U1.8 (VCC2), U4.1 (VDD), U4.17 (VDD), U6.8 (VCC)
ADDR1: R3.1, U4.14 (PB0), U6.1 (E0)
ADDR2: R4.1, U4.15 (PB1), U6.2 (E1)
ADDR3: R5.1, U4.26 (PB3), U6.3 (E2)
Boot0: J4.2, U4.31 (BOOT0)
CCLed: D6.1 (K), Q7.3 (C)
CL_PD: Q6.3 (C), R63.2, R68.1
Crystal_IN: C6.2, U4.2 (PF0), Y1.2
Crystal_OUT: C7.2, U4.3 (PF1), Y1.1
EN_Vout: D4.2 (A), R1.1, U4.22 (PA12)
Enable: R51.2, U4.21 (PA11), U13.4
Error: D5.2 (A), J9.2, U4.23 (PA13)
GND: C1.2, C2.2, C3.2, C4.2, C5.2, C6.1, C7.1, C8.2, C9.2, C10.2, C11.2, C12.2, C13.2, C14.2, C16.2, C17.2, C18.2, C19.2, C23.2, C24.2, C25.2, C26.2, C27.2, C28.2, C30.2, C31.2, C32.2, C33.2, C34.2, C35.2, C36.1, C37.2, C38.1, D1.2 (A), D2.4 (K), D8.2 (A), F4.2, J1.1, J2.1, J3.1, J4.3, J5.2, J8.1, J9.4, Q2.1 (E), Q3.1 (E), Q4.1 (E), Q5.1 (E), Q6.1 (E), Q7.1 (E), R2.2, R7.1, R8.2, R11.1, R12.1, R14.1, R21.2, R24.2, R25.1, R26.1, R27.1, R49.1, R54.1, R56.2, R57.1, R66.1, R70.1, SW1.2, U1.5 (GND2), U2.4 (GND), U3.11 (GND), U4.16 (VSS), U4.32 (VSS), U5.11 (GND), U6.4 (VSS), U8.1 (V-), U10.1 (V-), U11.4 (V-), U12.2, U13.3, U15.4 (V-), U16.3
Galv_Enable: J6.22, R69.1
Galv_GND: C15.2, J6.19, U1.4 (GND1), U12.3, U13.2
Galv_Interrupt: J6.21, R50.2, U12.4
Galv_SCL: J6.17, U1.3 (SCL1)
Galv_SDA: J6.18, U1.2 (SDA1)
Galv_Vcc: C15.1, J6.20, Q8.2 (E), R50.1, U1.1 (VCC1)
Interrupt: R43.1, U4.10 (PA4)
NRST: C12.1, SW1.1, U4.4 (NRST)
unnamed: C3.1, U3.3 (INTVcc)
unnamed: C9.1, U3.7 (TR/SS)
unnamed: C11.1, R1.2, U5.5 (RUN/SS)
unnamed: C14.1, R6.2, U5.9 (Vcontrol)
unnamed: C17.1, R6.1
unnamed: C20.1, U3.1 (BST)
unnamed: C20.2, L1.1, U3.2 (SW)
unnamed: C21.1, R8.1, R9.1, U3.6 (FB)
unnamed: C22.1, U5.2 (BOOST)
unnamed: C22.2, D1.1 (K), L2.1, U5.3 (SW)
unnamed: C32.1, D7.1 (K), F1.2, U14.4 (Vcontol), U14.5 (Vin)
unnamed: D2.1 (RA), R28.1
unnamed: D2.2 (GA), R29.1
unnamed: D2.3 (BA), R30.1
unnamed: D3.1 (K), R25.2
unnamed: D4.1 (K), R26.2
unnamed: D5.1 (K), R27.2
unnamed: D9.1 (K), R32.1, RL1.1 (L1)
unnamed: D9.2 (A), Q2.3 (C), RL1.2 (L2)
unnamed: D10.1 (K), R48.1, RL2.1 (L1)
unnamed: D10.2 (A), Q3.3 (C), RL2.2 (L2)
unnamed: D11.1 (K), R55.1, RL3.1 (L1)
unnamed: D11.2 (A), Q4.3 (C), RL3.2 (L2)
unnamed: D12.1 (K), R64.1, RL4.1 (L1)
unnamed: D12.2 (A), Q5.3 (C), RL4.2 (L2)
unnamed: F1.1, R33.2, R34.2, R35.2, R36.2, R37.2, R38.2, R39.2, R40.2, R41.2, R42.2, U11.5 (+)
unnamed: F2.1, RL1.3 (R2), RL2.3 (R2)
unnamed: F4.1, RL3.3 (R2), RL4.3 (R2)
unnamed: J1.2, R3.2
unnamed: J2.2, R4.2
unnamed: J3.2, R5.2
unnamed: Q1.2 (G), R18.2
unnamed: Q1.3 (D), R14.2, R17.2, U5.8 (FB)
unnamed: Q2.2 (B), R31.2
unnamed: Q3.2 (B), R45.2
unnamed: Q4.2 (B), R60.2
unnamed: Q5.2 (B), R71.2
unnamed: Q6.2 (B), R61.2
unnamed: Q7.2 (B), R62.2
unnamed: Q8.1 (B), R69.2
unnamed: Q8.3 (C), R44.1
unnamed: R2.1, U3.4 (RT)
unnamed: R7.2, U5.10 (RT)
unnamed: R19.1, U7.2
unnamed: R19.2, R20.1, U8.3 (ADJ)
unnamed: R22.1, U9.2
unnamed: R22.2, R23.1, U10.3 (ADJ)
unnamed: R43.2, U12.1
unnamed: R44.2, U13.1
unnamed: R46.1, U11.6 (-), U11.7
unnamed: R46.2, R52.1, U11.2 (-)
unnamed 72: R47.2, R49.2, U11.3 (+); also elsewhere on the board
unnamed: R52.2, R53.1, U11.1
unnamed: R56.1, U16.2
unnamed: R57.2, R58.1, R59.1, U15.2 (-)
unnamed: R61.1, R62.1, U15.7
unnamed: R63.1, U15.1
unnamed: U7.3, U8.2 (V+)
unnamed: U9.3, U10.2 (V+)
Pgood 3.3v: R13.2, U3.8 (PG)
Pgood Vout: R10.2, U5.7 (PG)
REF-3V: C16.1, U2.6 (OUT), U4.5 (VDDA)
RGB_B: R30.2, U4.29 (PB6)
RGB_G: R29.2, U4.28 (PB5)
RGB_R: R28.2, U4.27 (PB4)
Relay1: R11.2, R31.1, U4.13 (PA7)
Relay2: R12.2, R45.1, U4.18 (PA8)
Relay3: R54.2, R60.1, U4.19 (PA9)
Relay4: R70.2, R71.1, U4.20 (PA10)
SCL: R16.2, U1.6 (SCL2), U4.25 (PA15), U6.6 (SCL)
SDA: R15.2, U1.7 (SDA2), U4.30 (PB7), U6.5 (SDA)
SWCLK: J9.3, R10.1, U4.24 (PA14)
Temp_1: R20.2, R21.1, U4.8 (PA2)
Temp_2: R23.2, R24.1, U4.9 (PA3)
V+: C24.1, C26.1, C27.1, C30.1, C33.1, C37.1, L2.2, Q1.1 (S), R17.1, R33.1, R34.1, R35.1, R36.1, R37.1, R38.1, R39.1, R40.1, R41.1, R42.1, R47.1, U5.1 (BD), U11.8 (V+), U15.8 (V+); also elsewhere on the board
Vin: C1.1, C2.1, C4.1, C5.1, C8.1, C10.1, C13.1, C18.1, D3.2 (A), F3.2, R32.2, R48.2, R55.2, R64.2, U2.2 (Vin), U2.3 (~SHDN), U3.9 (Vin), U3.10 (EN/UV), U5.4 (Vin), U7.1, U9.1
Vin Polly: F3.1, J5.1
Virt-Bus1: J6.33, J6.34, J6.35, J6.36, J6.37, J6.38, J6.39, J6.40, RL1.4 (R1), RL3.4 (R1)
Virt-Bus2: J6.25, J6.26, J6.27, J6.28, J6.29, J6.30, J6.31, J6.32, RL2.4 (R1), RL4.4 (R1)
Vout: C35.1, D7.2 (A), D8.1 (K), F2.2, J7.1, R18.1, R65.2, R67.2, U14.3 (Out), U16.1
Vout_ADC: C38.2, R65.1, R66.2, R67.1, U4.6 (PA0)
Vout_DAC: U4.11 (PA5), U15.3 (+)
Vref_LDO: C34.1, R58.2, R59.2, R68.2, U14.2 (Set)

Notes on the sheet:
Address selection
I2C Isolator
Voltage refrence
3.3V 500mA Buck converter
I2C EEPromChip
STM32 microcontroller
Output 3.5A Buck converter 1.8Mhz Swiching Freq
Temperature sensors
Led's
Opto isolator
Current Sense IinLDO ~~ IoutLDO 0-3A 0-3V
Supply OpAmps
Minimum load LM3083 1mA Const
Over Voltage Protection
Output Connectors
Vout sense 0-30V 0-3Vout
Voltage control 0-3V In
Current Limter 0-3A 0-3V
liniar voltage dropout and feedback 3A 0-20V
Vbus Relais

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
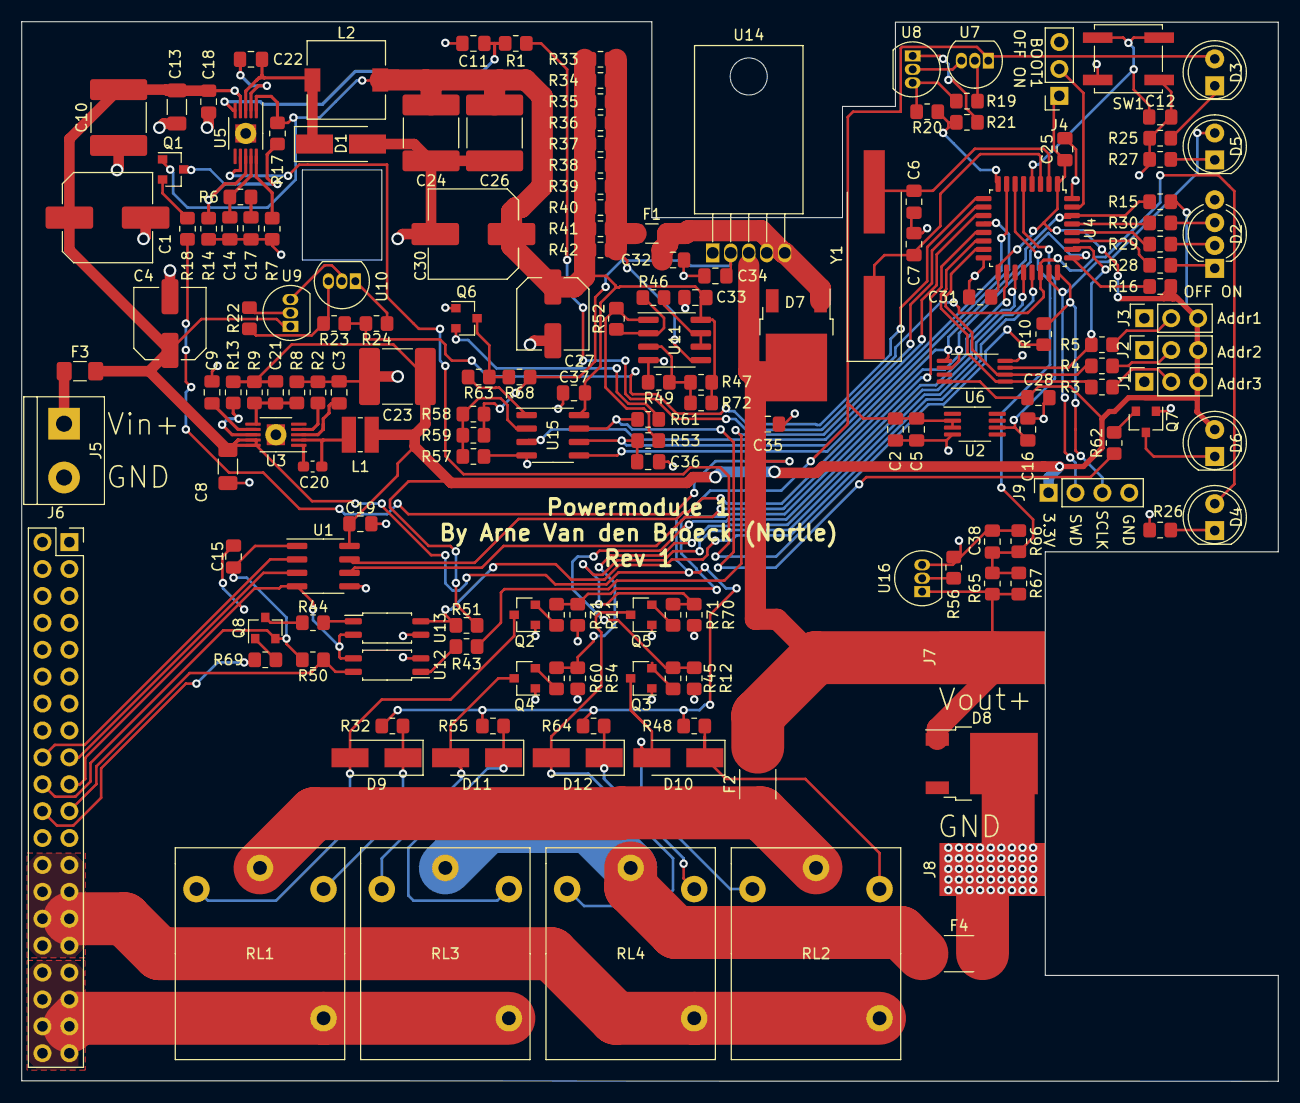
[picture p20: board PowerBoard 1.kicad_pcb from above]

Board: 2 copper layers, 118.7 x 100.0 mm, 166 parts (0 on the bottom side), 106 nets.

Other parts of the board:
R72: 2Kohm; R_0805_2012Metric_Pad1.20x1.40mm_HandSolder

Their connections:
unnamed 72: R72.2; also elsewhere on the board
V+: R72.1; also elsewhere on the board

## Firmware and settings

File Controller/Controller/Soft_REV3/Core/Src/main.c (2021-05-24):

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
/* Includes ------------------------------------------------------------------*/
#include "main.h"
#include "cmsis_os.h"
#include "app_touchgfx.h"

/* USER CODE BEGIN PD */
#define IS42S16400J_SIZE 0x400000
#define SDRAM_REFRESH_COUNT 1539
#define SDRAM_ADDR 0xC0000000
#define SDRAM_ADDR_SWP 0x80000000
#define SDRAM_BANK FMC_Bank1_SDRAM

#define SDRAM_TIMEOUT 								((uint32_t)0xFFFF)
#define SDRAM_MODEREG_BURST_LENGTH_1 				((uint16_t)0x0000)
#define SDRAM_MODEREG_BURST_LENGTH_2 				((uint16_t)0x0001)
#define SDRAM_MODEREG_BURST_LENGTH_4 				((uint16_t)0x0002)
#define SDRAM_MODEREG_BURST_LENGTH_8 				((uint16_t)0x0003)
#define SDRAM_MODEREG_BURST_TYPE_SEQUENTIAL 		((uint16_t)0x0007)
#define SDRAM_MODEREG_BURST_TYPE_INTERLEAVED 		((uint16_t)0x0008)
#define SDRAM_MODEREG_CAS_LATENCY_2 				((uint16_t)0x0020)
#define SDRAM_MODEREG_CAS_LATENCY_3 				((uint16_t)0x0030)
#define SDRAM_MODEREG_OPERATING_MODE_STANDARD 		((uint16_t)0x0000)
#define SDRAM_MODEREG_WRITEBURST_MODE_PROGRAMMED 	((uint16_t)0x0000)
#define SDRAM_MODEREG_WRITEBURST_MODE_SINGLE 		((uint16_t)0x0200)

#define WRITE_SDRAM_32(address, word) (*( uint32_t*) (address + 4)) = word

/* LCD Defines And Vars */

#define DisplayBufferLenght 1024*600*3
uint16_t* framebuffer = (uint16_t*)0xC0000000;

/* USER CODE END PD */


CRC_HandleTypeDef hcrc;

DMA2D_HandleTypeDef hdma2d;

I2C_HandleTypeDef hi2c3;
I2C_HandleTypeDef hi2c4;

LTDC_HandleTypeDef hltdc;

UART_HandleTypeDef huart1;

SDRAM_HandleTypeDef hsdram1;

/* Definitions for HardwareTask */
osThreadId_t HardwareTaskHandle;
const osThreadAttr_t HardwareTask_attributes = {
  .name = "HardwareTask",
  .stack_size = 512 * 4,
  .priority = (osPriority_t) osPriorityNormal,
};
/* Definitions for TouchGFXTask */
osThreadId_t TouchGFXTaskHandle;
const osThreadAttr_t TouchGFXTask_attributes = {
  .name = "TouchGFXTask",
  .stack_size = 8192 * 4,
  .priority = (osPriority_t) osPriorityNormal,
};
void SystemClock_Config(void);
static void MX_GPIO_Init(void);
static void MX_LTDC_Init(void);
static void MX_FMC_Init(void);
static void MX_DMA2D_Init(void);
static void MX_CRC_Init(void);
static void MX_I2C3_Init(void);
static void MX_USART1_UART_Init(void);
static void MX_I2C4_Init(void);
void StartHardwareTask(void *argument);
void StartGFXTask(void *argument);

/* USER CODE BEGIN 0 */

#include <errno.h>
#include <sys/stat.h>
#include <sys/times.h>
#include <sys/unistd.h>
int _write(int file, char *ptr, int len) {
    HAL_StatusTypeDef xStatus;
    switch (file) {
    case STDOUT_FILENO: /*stdout*/
		xStatus = HAL_UART_Transmit(&huart1, (uint8_t*)ptr, len, HAL_MAX_DELAY);
		if (xStatus != HAL_OK) {
			errno = EIO;
			return -1;
		}
        break;
    case STDERR_FILENO: /* stderr */
		xStatus = HAL_UART_Transmit(&huart1, (uint8_t*)ptr, len, HAL_MAX_DELAY);
		if (xStatus != HAL_OK) {
			errno = EIO;
			return -1;
		}
        break;
    default:
        errno = EBADF;
        return -1;
    }
    return len;
}

void twiScan(void)
{
uint8_t Buffer[25] = {0};
uint8_t Space[] = " - ";
uint8_t StartMSG[] = "Starting I2C Scanning: \r\n";
uint8_t EndMSG[] = "Done! \r\n\r\n";

uint8_t i = 0, ret;

HAL_Delay(1000);
/*-[ I2C Bus Scanning ]-*/
HAL_UART_Transmit(&huart1, StartMSG, sizeof(StartMSG), 10000);
for(i=1; i<128; i++)
{
	ret = HAL_I2C_IsDeviceReady(&hi2c4, (uint16_t)(i<<1), 3, 5);
	if (ret != HAL_OK) /* No ACK Received At That Address */
	{
	    HAL_UART_Transmit(&huart1, Space, sizeof(Space), 10000);
    }
	else if(ret == HAL_OK)
	{
	    sprintf(Buffer, "0x%X", i);
	    HAL_UART_Transmit(&huart1, Buffer, sizeof(Buffer), 10000);
	}
}
HAL_UART_Transmit(&huart1, EndMSG, sizeof(EndMSG), 10000);
/*--[ Scanning Done ]--*/
}

/* USER CODE END 0 */

/**
  * @brief  The application entry point.
  * @retval int
  */
int main(void)
{
  /* Enable D-Cache---------------------------------------------------------*/
  SCB_EnableDCache();

  /* MCU Configuration--------------------------------------------------------*/

  /* Reset of all peripherals, Initializes the Flash interface and the Systick. */
  HAL_Init();

  /* Configure the system clock */
  SystemClock_Config();

  /* Initialize all configured peripherals */
  MX_GPIO_Init();
  MX_LTDC_Init();
  MX_FMC_Init();
  MX_DMA2D_Init();
  MX_CRC_Init();
  MX_I2C3_Init();
  MX_USART1_UART_Init();
  MX_I2C4_Init();
  MX_TouchGFX_Init();
  /* USER CODE BEGIN 2 */

  HAL_Delay(300);
  HAL_GPIO_WritePin(LCD_Baclight_GPIO_Port,LCD_Baclight_Pin,GPIO_PIN_SET);
  //uint32_t* framebuffer = (uint32_t*)0xC0000000;
  //Clear LCD buffer
  //for(uint32_t i = 0;i < 160000;i++){
  //	 framebuffer[i] = i;
  //	HAL_Delay(1);
  //}
  HAL_Delay(1000);
  //twiScan();
  uint16_t X,Y;
  uint8_t Pressure,Touch;
  /* USER CODE END 2 */

  /* Init scheduler */
  osKernelInitialize();

  /* USER CODE BEGIN RTOS_MUTEX */
  /* add mutexes, ... */
  /* USER CODE END RTOS_MUTEX */

  /* USER CODE BEGIN RTOS_SEMAPHORES */
  /* add semaphores, ... */
  /* USER CODE END RTOS_SEMAPHORES */

  /* USER CODE BEGIN RTOS_TIMERS */
  /* start timers, add new ones, ... */
  /* USER CODE END RTOS_TIMERS */

  /* USER CODE BEGIN RTOS_QUEUES */
  /* add queues, ... */

  /* USER CODE END RTOS_QUEUES */

  /* Create the thread(s) */
  /* creation of HardwareTask */
  HardwareTaskHandle = osThreadNew(StartHardwareTask, NULL, &HardwareTask_attributes);

  /* creation of TouchGFXTask */
  TouchGFXTaskHandle = osThreadNew(StartGFXTask, NULL, &TouchGFXTask_attributes);

  /* USER CODE BEGIN RTOS_THREADS */
  /* add threads, ... */
  /* USER CODE END RTOS_THREADS */

  /* USER CODE BEGIN RTOS_EVENTS */
  /* add events, ... */
  /* USER CODE END RTOS_EVENTS */

  /* Start scheduler */
  osKernelStart();

  /* We should never get here as control is now taken by the scheduler */
  /* Infinite loop */
  /* USER CODE BEGIN WHILE */
  while (1)
  {
    /* USER CODE END WHILE */

    /* USER CODE BEGIN 3 */

  //GetTouchPoint(&hi2c3,0x38,1,&X,&Y,&Touch,&Pressure);

  }
  /* USER CODE END 3 */
}

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
/* USER CODE BEGIN 4 */

void MX_SDRAM_InitSeqeunce(uint32_t RefreshCount,uint32_t timout){
	__IO uint32_t tmpmrd = 0;
	static FMC_SDRAM_CommandTypeDef Command;

	Command.CommandMode 			= FMC_SDRAM_CMD_CLK_ENABLE;
	Command.CommandTarget  			= FMC_SDRAM_CMD_TARGET_BANK1;
	Command.AutoRefreshNumber		= 1;
	Command.ModeRegisterDefinition 	= 0;

	HAL_SDRAM_SendCommand(&hsdram1, &Command, timout);

	HAL_Delay(1);

	Command.CommandMode 			= FMC_SDRAM_CMD_PALL;
	Command.CommandTarget  			= FMC_SDRAM_CMD_TARGET_BANK1;
	Command.AutoRefreshNumber		= 1;
	Command.ModeRegisterDefinition 	= 0;

	HAL_SDRAM_SendCommand(&hsdram1, &Command, timout);

	Command.CommandMode 			= FMC_SDRAM_CMD_AUTOREFRESH_MODE;
	Command.CommandTarget  			= FMC_SDRAM_CMD_TARGET_BANK1;
	Command.AutoRefreshNumber		= 8;
	Command.ModeRegisterDefinition 	= 0;

	HAL_SDRAM_SendCommand(&hsdram1, &Command, timout);

    tmpmrd = (uint32_t)SDRAM_MODEREG_BURST_LENGTH_1          |
					   SDRAM_MODEREG_BURST_TYPE_SEQUENTIAL   |
					   SDRAM_MODEREG_CAS_LATENCY_3           |
					   SDRAM_MODEREG_WRITEBURST_MODE_SINGLE;

	Command.CommandMode 			= FMC_SDRAM_CMD_LOAD_MODE;
	Command.CommandTarget  			= FMC_SDRAM_CMD_TARGET_BANK1;
	Command.AutoRefreshNumber		= 1;
	Command.ModeRegisterDefinition 	= tmpmrd;

	HAL_SDRAM_SendCommand(&hsdram1, &Command, timout);

	HAL_SDRAM_ProgramRefreshRate(&hsdram1, RefreshCount);
}
/* USER CODE END 4 */

/* USER CODE BEGIN Header_StartHardwareTask */
/**
  * @brief  Function implementing the HardwareTask thread.
  * @param  argument: Not used
  * @retval None
  */
/* USER CODE END Header_StartHardwareTask */
void StartHardwareTask(void *argument)
{
  /* USER CODE BEGIN 5 */
  /* Infinite loop */
  for(;;)
  {
    osDelay(100);
  }
  /* USER CODE END 5 */
}

/* USER CODE BEGIN Header_StartGFXTask */
/**
* @brief Function implementing the TouchGFXTask thread.
* @param argument: Not used
* @retval None
*/
/* USER CODE END Header_StartGFXTask */
void StartGFXTask(void *argument)
{
  /* USER CODE BEGIN StartGFXTask */

  MX_TouchGFX_Process();
  /* Infinite loop */
  for(;;)
  {
    osDelay(1);
  }
  /* USER CODE END StartGFXTask */
}

 /**
  * @brief  Period elapsed callback in non blocking mode
  * @note   This function is called  when TIM6 interrupt took place, inside
  * HAL_TIM_IRQHandler(). It makes a direct call to HAL_IncTick() to increment
  * a global variable "uwTick" used as application time base.
  * @param  htim : TIM handle
  * @retval None
  */
void HAL_TIM_PeriodElapsedCallback(TIM_HandleTypeDef *htim)
{
  if (htim->Instance == TIM6) {
    HAL_IncTick();
  }
}

/**
  * @brief  This function is executed in case of error occurrence.
  * @retval None
  */
void Error_Handler(void)
{
  /* USER CODE BEGIN Error_Handler_Debug */
  /* User can add his own implementation to report the HAL error return state */
  __disable_irq();
  while (1)
  {
  }
  /* USER CODE END Error_Handler_Debug */
}

#ifdef  USE_FULL_ASSERT
/**
  * @brief  Reports the name of the source file and the source line number
  *         where the assert_param error has occurred.
  * @param  file: pointer to the source file name
  * @param  line: assert_param error line source number
  * @retval None
  */
void assert_failed(uint8_t *file, uint32_t line)
{
  /* USER CODE BEGIN 6 */
  /* User can add his own implementation to report the file name and line number,
     ex: printf("Wrong parameters value: file %s on line %d\r\n", file, line) */
  /* USER CODE END 6 */
}
#endif /* USE_FULL_ASSERT */

/************************ (C) COPYRIGHT STMicroelectronics *****END OF FILE****/

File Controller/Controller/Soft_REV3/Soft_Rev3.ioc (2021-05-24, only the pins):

PH12.Signal=I2C4_SDA
PG8.Signal=FMC_SDCLK
PG4.Signal=FMC_A14_BA0
PG0.Signal=FMC_A10
PG13.Signal=LTDC_R0
PH9.Signal=LTDC_R3
PH1/OSC_OUT.Signal=RCC_OSC_OUT
PC3.Signal=FMC_SDCKE0
PD0.Signal=FMC_D2_DA2
PD8.Signal=FMC_D13_DA13
PE5.Signal=LTDC_G0
PE1.Signal=FMC_NBL1
PE9.Signal=FMC_D6_DA6
PI3.Signal=GPIO_Output
PA8.Signal=LTDC_R6
PF3.Signal=FMC_A3
PE10.Signal=FMC_D7_DA7
PB9.Signal=LTDC_B7
PD12.Signal=I2C4_SCL
PA10.Signal=USART1_RX
PF14.Signal=FMC_A8
PD15.Signal=FMC_D1_DA1
PG12.Signal=LTDC_B1
PH15.Signal=LTDC_G4
PH13.Signal=LTDC_G2
PG5.Signal=FMC_A15_BA1
PC13.Signal=GPIO_Output
PC2.Signal=FMC_SDNE0
PD7.Signal=GPIO_Output
PD1.Signal=FMC_D3_DA3
PC0.Signal=FMC_SDNWE
PG10.Signal=LTDC_B2
PF8.GPIO_Label=LCD_CT_RESET
PD10.Signal=FMC_D15_DA15
PI8.GPIO_Label=LCD_SHLR
PA9.Signal=USART1_TX
PI7.Signal=GPIO_Output
PE14.Signal=FMC_D11_DA11
PE15.Signal=FMC_D12_DA12
PE8.Signal=FMC_D5_DA5
PI1.Signal=LTDC_G6
PI2.Signal=LTDC_G7
PF13.Signal=FMC_A7
PF9.Signal=GPIO_Input
PE3.Signal=GPIO_Output
PC15/OSC32_OUT.Signal=RCC_OSC32_OUT
PF4.Signal=FMC_A4
PG6.Signal=LTDC_R7
Mcu.UserName=STM32F746IGTx
PH14.Signal=LTDC_G3
PH10.Signal=LTDC_R4
PC10.Signal=LTDC_R2
PC13.GPIO_Label=LCD_DITHUB
PG11.Signal=LTDC_B3
PG15.Signal=FMC_SDNCAS
PF12.Signal=FMC_A6
PI8.Signal=GPIO_Output
PE13.Signal=FMC_D10_DA10
PI5.Signal=LTDC_B5
PI0.Signal=LTDC_G5
PF11.Signal=FMC_SDNRAS
PE4.Signal=LTDC_B0
PD7.GPIO_Label=LCD_Mode
PC14/OSC32_IN.Signal=RCC_OSC32_IN
PF8.Signal=GPIO_Output
PF5.Signal=FMC_A5
PH7.Signal=I2C3_SCL
PF0.Signal=FMC_A0
PE7.Signal=FMC_D4_DA4
PG7.Signal=LTDC_CLK
PH11.Signal=LTDC_R5
PG1.Signal=FMC_A11
PI10.Signal=LTDC_HSYNC
PD9.Signal=FMC_D14_DA14
PA13.Signal=SYS_JTMS-SWDIO
PH8.Signal=I2C3_SDA
PF2.Signal=FMC_A2
PE11.Signal=FMC_D8_DA8
PI9.Signal=LTDC_VSYNC
PH0/OSC_IN.Signal=RCC_OSC_IN
PF10.Signal=LTDC_DE
PI4.Signal=LTDC_B4
PI7.GPIO_Label=LCD_RESET
PF15.Signal=FMC_A9
PF1.Signal=FMC_A1
PE6.Signal=LTDC_G1
PE0.Signal=FMC_NBL0
PE12.Signal=FMC_D9_DA9
PD14.Signal=FMC_D0_DA0
PA14.Signal=SYS_JTCK-SWCLK
PH3.Signal=LTDC_R1
PI3.GPIO_Label=LCD_Baclight
PB8.Signal=LTDC_B6
PE3.GPIO_Label=LCD_UPDN

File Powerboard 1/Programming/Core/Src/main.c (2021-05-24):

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
/* Includes ------------------------------------------------------------------*/
#include "main.h"
#include "adc.h"
#include "dac.h"
#include "i2c.h"
#include "gpio.h"


/* USER CODE BEGIN PV */
uint8_t I2CAddress;
uint16_t SetVoltage, SetAmprage, CalibrationVolate, CalibrationAmprage;
uint16_t ReadVoltage, ReadAmprage;
uint8_t Enable = 0, ContolReg, Identify;

/* USER CODE END PV */

void SystemClock_Config(void);
/* USER CODE BEGIN 0 */

uint8_t Buff[10];
uint8_t DataBuff[14];
enum State
{
  GetReg,
  GettingData
};
enum State TransferState = GetReg;
uint8_t SelectedReg;

void HAL_I2C_AddrCallback(I2C_HandleTypeDef *hi2c, uint8_t direction, uint16_t addrMatchCode)
{
  switch (direction)
  {
  case I2C_DIRECTION_TRANSMIT:
    if (HAL_I2C_Slave_Seq_Receive_IT(hi2c, Buff, 1, I2C_FIRST_FRAME) != HAL_OK)
    {
      //	I2C_Error_Handler();
    }

    break;
  case I2C_DIRECTION_RECEIVE:
    DataBuff[0] = ContolReg;
    DataBuff[1] = Enable;
    DataBuff[2] = SetVoltage & 0xff;
    DataBuff[3] = (SetVoltage & 0xff00) >> 8;
    DataBuff[4] = SetAmprage & 0xff;
    DataBuff[5] = (SetAmprage & 0xff00) >> 8;
    DataBuff[6] = CalibrationVolate & 0xff;
    DataBuff[7] = (CalibrationVolate & 0xff00) >> 8;
    DataBuff[8] = CalibrationAmprage & 0xff;
    DataBuff[9] = (CalibrationAmprage & 0xff00) >> 8;
    DataBuff[10] = ReadVoltage & 0xff;
    DataBuff[11] = (ReadVoltage & 0xff00) >> 8;
    DataBuff[12] = ReadAmprage & 0xff;
    DataBuff[13] = (ReadAmprage & 0xff00) >> 8;
    if (HAL_I2C_Slave_Seq_Transmit_IT(hi2c, &DataBuff, 14, I2C_FIRST_AND_LAST_FRAME) != HAL_OK)
    {
      //I2C_Error_Handler();
    }
    break;
  default:
    //I2C_Error_Handler();
    break;
  }
}

void HAL_I2C_SlaveRxCpltCallback(I2C_HandleTypeDef *HI2C)
{
  //I2Chandler(HI2C);
  if (TransferState == GetReg)
  {
    switch (Buff[0])
    {
    case 0x01:
      HAL_I2C_Slave_Seq_Receive_IT(HI2C, Buff, 1, I2C_LAST_FRAME);
      SelectedReg = 0x01;
      break;
    case 0x02:
      HAL_I2C_Slave_Seq_Receive_IT(HI2C, Buff, 1, I2C_LAST_FRAME);
      SelectedReg = 0x02;
      break;
    case 0x10:
      HAL_I2C_Slave_Seq_Receive_IT(HI2C, Buff, 2, I2C_LAST_FRAME);
      SelectedReg = 0x10;
      break;
    case 0x11:
      HAL_I2C_Slave_Seq_Receive_IT(HI2C, Buff, 2, I2C_LAST_FRAME);
      SelectedReg = 0x11;
      break;
    case 0x12:
      HAL_I2C_Slave_Seq_Receive_IT(HI2C, Buff, 2, I2C_LAST_FRAME);
      SelectedReg = 0x12;
      break;
    case 0x13:
      HAL_I2C_Slave_Seq_Receive_IT(HI2C, Buff, 2, I2C_LAST_FRAME);
      SelectedReg = 0x13;
      break;
    default:
      HAL_I2C_ErrorCallback(HI2C);
      break;
    }
    TransferState = GettingData;
  }
  else
  {
    switch (SelectedReg)
    {
    case 0x01:
      if (Buff[0] < 250)
      {
        Enable = 0;
      }
      else
      {
        Enable = 1;
      }
      break;
    case 0x02:
      if (Buff[0] < 250)
      {
        Identify = 0;
      }
      else
      {
        Identify = 1;
      }
      break;
    case 0x10:
      SetVoltage = Buff[0] || (Buff[1] << 8);
      break;
    case 0x11:
      CalibrationVolate = Buff[0] || (Buff[1] << 8);
      break;
    case 0x12:
      SetAmprage = Buff[0] || (Buff[1] << 8);
      break;
    case 0x13:
      CalibrationAmprage = Buff[0] || (Buff[1] << 8);
      break;
    default:
      HAL_I2C_ErrorCallback(HI2C);
      break;
    }
    TransferState = GetReg;
  }
}

void HAL_I2C_ListenCpltCallback(I2C_HandleTypeDef *hi2c)
{
  HAL_I2C_EnableListen_IT(hi2c);
}

void HAL_I2C_ErrorCallback(I2C_HandleTypeDef *hi2c)
{
  if (HAL_I2C_GetError(hi2c) != HAL_I2C_ERROR_AF)
  {
    I2C_Error_Handler();
  }
}

void I2C_Error_Handler()
{
  //_error_handler();
}
/* USER CODE END 0 */

/**
  * @brief  The application entry point.
  * @retval int
  */
int main(void)
{
  /* MCU Configuration--------------------------------------------------------*/

  /* Reset of all peripherals, Initializes the Flash interface and the Systick. */
  HAL_Init();

  /* Configure the system clock */
  SystemClock_Config();

  /* Initialize all configured peripherals */
  MX_GPIO_Init();
  MX_ADC1_Init();
  MX_ADC2_Init();
  MX_DAC1_Init();
  MX_DAC2_Init();
  MX_I2C1_Init();
  /* USER CODE BEGIN 2 */
  //HAL_Delay(1000);
  //HAL_DAC_Start(&hdac1,DAC_CHANNEL_2);
  //HAL_DAC_SetValue(&hdac1,DAC_CHANNEL_2,DAC_ALIGN_12B_R,200);
  //HAL_DAC_Start(&hdac2,DAC_CHANNEL_1);
  HAL_DAC_SetValue(&hdac2,DAC_CHANNEL_1,DAC_ALIGN_12B_R,1000);
  //HAL_GPIO_WritePin(En_Vout_GPIO_Port,En_Vout_Pin,GPIO_PIN_SET);

  ReadVoltage = 2222;
  HAL_I2C_EnableListen_IT(&hi2c1);
  //HAL_I2C_Slave_Receive_IT(&hi2c1,Buff,1);

  //I2CStart(&hi2c1);
  uint8_t Read1, Read2;
  /* USER CODE END 2 */

  /* Infinite loop */
  /* USER CODE BEGIN WHILE */
  while (1)
  {
    /* USER CODE END WHILE */
    if (Enable == 1)
    {
      HAL_GPIO_WritePin(En_Vout_GPIO_Port, En_Vout_Pin, GPIO_PIN_SET);
    }
    else
    {
      HAL_GPIO_WritePin(En_Vout_GPIO_Port, En_Vout_Pin, GPIO_PIN_RESET);
    }
    if(SetVoltage < 2000){
    HAL_DAC_SetValue(&hdac1,DAC_CHANNEL_2,DAC_ALIGN_12B_R,SetVoltage);
    }
    /* USER CODE BEGIN 3 */
  }
  /* USER CODE END 3 */
}

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


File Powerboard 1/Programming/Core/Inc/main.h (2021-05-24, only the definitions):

#define VOUT_ADC_Pin GPIO_PIN_0
#define VOUT_ADC_GPIO_Port GPIOA
#define VOUT_ADCA1_Pin GPIO_PIN_1
#define VOUT_ADCA1_GPIO_Port GPIOA
#define TEMP1_Pin GPIO_PIN_2
#define TEMP1_GPIO_Port GPIOA
#define TEMP2_Pin GPIO_PIN_3
#define TEMP2_GPIO_Port GPIOA
#define Interrupt_Pin GPIO_PIN_4
#define Interrupt_GPIO_Port GPIOA
#define Vout_DAC_Pin GPIO_PIN_5
#define Vout_DAC_GPIO_Port GPIOA
#define Iout_DAC_Pin GPIO_PIN_6
#define Iout_DAC_GPIO_Port GPIOA
#define Relay1_Pin GPIO_PIN_7
#define Relay1_GPIO_Port GPIOA
#define ADDR1_Pin GPIO_PIN_0
#define ADDR1_GPIO_Port GPIOB
#define ADDR2_Pin GPIO_PIN_1
#define ADDR2_GPIO_Port GPIOB
#define Relay2_Pin GPIO_PIN_8
#define Relay2_GPIO_Port GPIOA
#define Relay3_Pin GPIO_PIN_9
#define Relay3_GPIO_Port GPIOA
#define Relay4_Pin GPIO_PIN_10
#define Relay4_GPIO_Port GPIOA
#define Enable_Pin GPIO_PIN_11
#define Enable_GPIO_Port GPIOA
#define En_Vout_Pin GPIO_PIN_12
#define En_Vout_GPIO_Port GPIOA
#define I2C_SCL_Pin GPIO_PIN_15
#define I2C_SCL_GPIO_Port GPIOA
#define ADDR3_Pin GPIO_PIN_3
#define ADDR3_GPIO_Port GPIOB
#define RGB_R_Pin GPIO_PIN_4
#define RGB_R_GPIO_Port GPIOB
#define RGB_G_Pin GPIO_PIN_5
#define RGB_G_GPIO_Port GPIOB
#define RGB_B_Pin GPIO_PIN_6
#define RGB_B_GPIO_Port GPIOB
#define I2C_SDA_Pin GPIO_PIN_7
#define I2C_SDA_GPIO_Port GPIOB

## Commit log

2021-03-07 Power supply module REV 1
    Adding the power supply module to the GIT
    [PowerBoard 1-B_Cu.gbr, PowerBoard 1-B_Mask.gbr, PowerBoard 1-B_Paste.gbr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]
2021-03-07 Lcd Board REV 1
    Adding Lcd Board to the GIT
    [LCD.kicad_sch, LCDboard Front.kicad_pcb, LCDboard Front.kicad_sch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]
2021-03-09 changed LCDboard to Controller
    [Controller Front.kicad_pcb, Controller Front.kicad_sch, Controller.kicad_pcb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]
2021-03-11 Rev 1 LCD contoller board
    [Controller.kicad_pcb, Controller.kicad_sch, LCD.kicad_sch]
2021-03-14 contoller and contoller front Rev 1
    [Controller Front.kicad_pcb, Controller.kicad_pcb, Controller.kicad_sch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]
2021-03-14 updated powerboard front to remove copper
    [Powerboard 1 Front.kicad_pcb]
2021-03-14 added some gerbers
    [Controller Front-B_Cu.gbr, Controller Front-B_Mask.gbr, Controller Front-B_Paste.gbr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]
2021-03-16 ReV 2 of the contoller Board
    [Controller.kicad_pcb, Controller.kicad_sch]
2021-03-16 Updated Gerbers
2021-03-16 Add TouchGFX project
    [texts.xlsx]
2021-04-26 Rev 3 Pcb's
    [Controller Front-B_Cu.gbr, Controller Front-B_Mask.gbr, Controller Front-B_Paste.gbr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]
2021-05-24 Final Version Tested
    [BuckConv.kicad_sch, Buss.kicad_sch, CONNECTIONS.kicad_sch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]

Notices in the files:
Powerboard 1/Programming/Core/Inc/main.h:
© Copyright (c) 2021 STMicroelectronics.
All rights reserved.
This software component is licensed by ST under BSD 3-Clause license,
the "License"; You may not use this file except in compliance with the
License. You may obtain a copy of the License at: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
